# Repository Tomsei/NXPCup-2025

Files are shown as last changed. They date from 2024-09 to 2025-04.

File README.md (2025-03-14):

# NXPCup-2025
Software und Hardware für den NXP-Cup 2025
- **Software Ordner:** gesamter erzeugter Quellcode
- **Hardware Ordner:** Dokumentation der gewählten Hardware mitsamt Recherche

# NXP Cup
- ToDo: Beschreibung des NXP Cups...

Der NXP-Cup ist ein Internationaler Wettbewerb, ausgerichtet vom Unternehmen NXP (Link)...

# Styleguides
### Code
- Sprache (Variablen, Funktionen): Englisch
- Kommentare: Englisch
- Schreibweise: 
    - CamelCase
    - Funktionen / Variablen: starten klein
    - Typ-Klasse: starten groß
    - Variablen:
        - Boolen: Präfix is (isValid)
        - constant: konsequent großschreiben von CONSTANT
    - Leerzeichen zwischen Operatoren:  
    ```x + y``` anstatt ```a+y```; ```[x, y]``` anstatt ```[x,y]```
    - Klammerung: Klammer in gleicher Zeile dahinter
        ```
        function () {
            ...
        }
        ```
  - #defines werden komplett groß geschrieben ```#define NEW_DEFINE_VALUE```
### GIT
- Commits: Englisch
- Dateien: Englisch ```exmpleFileForDemonstration``` 
    - Der Name von Komponenten wird wenn notwendig mit _KOMPONENTENNAME an Datei angehangen
- Verzeichnisse: Englisch
- Wiki: Deutsch
- Issues: Deutsch

<br>
<br>

# Priorisierung der Veränderungen:
Aktuelle Übersicht über die überlegten Veränderungen und die Priorisierung dessen in der Umsetzung.

1. Neue Motoren (Brushless Motoren)
2. Ansteuerungsboard der Motoren (Geschwindigkeitsmessung, Motorkonfiguration)
3. Neue Kamera (Auswertung eines ganzen Bildes, wenn möglich höhere Auflösung
4. Fester Kameramast - Halterung sicherstellen!
5. Neuer Controller (Bevorzug Rasperry PI - Compute Module) → Leistungsstrak
6. Brake Out Board - Darauf kann dann das Compute Module hinterlegt werden
7. WLAN Stick
8. Eine Reihe von Neo LEDS zusammen schalten und nutzen
9. Display Hinzufügen
10. IMU
11. ABS (Durchdrehende Reifen)

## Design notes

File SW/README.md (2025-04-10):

# Software

Dokumentation von allen Erkenntnissen die im Bezug auf die SW des NXP-Cups entstanden sind

Die Ordner strukturieren hierbei die Entwicklungen auf der Kamera (Skripts und Firmwaremodul) und auf dem Teensy (PlattformIO Projekt). 

Im SW-Kit wird eine reduzierte version des Quellcodes festgehalten, der als Vorschlag für ein SW-Kit dienen kann.

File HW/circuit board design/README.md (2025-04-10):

# Platinenentwicklung

Hier werden die für die Platinen relevanten Dateien gespeichert. (Gerber sowie Projektdateien und Dokumentation)

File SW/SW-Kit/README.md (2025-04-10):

# Software-Kit

Das hier enthaltende PlatformIO Projekt und in OpenMV-Script hinterlegte Kameraskript sind die grundlegenden Basiselemente der Software. 

Sie stellen das von mir vorgeschlagene SW-Kit für zukünftige Studierende dar und bietet folgende Implementierung:

1. SPI Verbindung - OpenMV Cam: Die SPI-Verbindung der Kamera, die eine Übertragung von  5 Kamerazeilen durch das Kameraskript ```transferImageLinesSpi.py``` ausführt

2. SPI Verbindung - Teensy: Die Bibliotheksänderungen sowie die Kamera-Datei die zur Annahme der Bilddaten eingesetzt und benötigt werden. Hierbei handelt es sich nur um die reine SPI-Verbindung nicht um die weiteren vorgenommenen Optimierungne.

3. Driving Control - Basisansteuerung von Motor und Servo. 

4. Car Logic - Als Einstiegspunkt der Software / Steuerungen 

Drei und Vier sind auch gewhält worden um erste Ansätze einer möglichen Softwarestruktur aufzuzeigen, was wiederrum für zukünftige Studierende als Inspiration genutzt werden kann.

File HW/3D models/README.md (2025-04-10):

# 3D Modelle

Es liegen alle 3D Modelle in unterschiedlichen Dateiformaten vor. (nicht alle Modelle liegen nicht 3mf / stl vor (müssen noch eigenständig exportiert werden)
Die Freecad-Dateien können eigenständig bearbeitet werden um die 3D Modelle anzupassen.

Teilweise sind zusammengehörige Modelle in einer Datei umgesetzt worden

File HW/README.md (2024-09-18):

# Hardware

Dokumentation über alle Erkentnnisse bezüglich der Hardware.

## Recherche:
Die Recherche zu den unterschiedlichen Komponenten befindet sich im [Wiki des Repositorys](https://github.com/Tomsei/NXPCup-2025/wiki).

## 3D Modelle
Hier werden alle für das Kit notwendigen 3D Modelle gespeichert und notwendige Informationen gegeben.

## Platinendesign
Hier werden alle Platinenentwürfe und für die Platinen relevanten Dateien hinterlegt.

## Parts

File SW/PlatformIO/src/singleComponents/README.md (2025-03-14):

# Single Components
Jeglicher Quellcode dieses Ordners ist lediglich zum austesten der Einzelkomponenten und wird nicht in der finalen Software verwendet.

Dieser Ordner und alle Dateien die dieser beinhaltet sind Basistests der Komponenten, ohne weitere Struktur in der Programmierung. Er dient zum verifizieren, dass alle Komponenten **gleichzeitig** funktionsfähig und ansteuerbar sind.  

Auf der Kamera sollte das Script: ```controlEngineAccespointAsync.py``` ausgeführt werden. Somit kann auch die SPI Verbindung verifiziert werden, in dem das Steuersignal der Motoren weitergeleitet wird.

In der globalConfig.h muss folgende Definition stehen ```#define SINGLE_COMPONENTS_TEST ``` und die Definition zur Analyse auf der Kamera auskommentiert werden

In der Main Datei muss der folgender Quellcode ausgeführt werden:
```c++
#include <Arduino.h>
#include <Wire.h>

#include "configuration/globalConfig.h"
#include "singleComponents/teensy.h"
#include "singleComponents/opticalFlow_PIM453.h"
#include "singleComponents/tofDistanceMeasure_VL53L0X.h"
#include "singleComponents/irObstacleDetection_ARD_LINEFINDER.h"
#include "singleComponents/servo_REELYS2210.h"
#include "singleComponents/motor_PICHLERBOOST18S.h"
#include "singleComponents/imu_SEN0142.h"
#include "singleComponents/camera_OPENMVCAMRT1062.h"
#include "singleComponents/display_CS-ANAVI-DISPLAY1.h"
#include "singleComponents/ioExpander_MCP23017.h"
#include "singleComponents/poti.h"
#include "singleComponents/ledStrip_Adafruit1426.h"

//Just testing variable for engine control
bool globalEngineState;

void setup() {

  // put your setup code here, to run once:
  CONSOLE.begin(115200);
  Wire.begin();
  SingleComponent::setupOpticalFlow();
  SingleComponent::setupTofDistanceMeasure();
  SingleComponent::setupArdLinefinder();
  SingleComponent::setupImu();
  SingleComponent::setupServo();
  SingleComponent::setupMotor();
  SingleComponent::setupCamera();
  SingleComponent::setupDisplay();
  SingleComponent::setupIoExpander();
  SingleComponent::setupLedStrip();

  //Just testing variable
  globalEngineState = false;
}

void loop() {
  // put your main code here, to run repeatedly:
  SingleComponent::runOpticalFlow();
  SingleComponent::runTofDistanceMeasure();
  SingleComponent::runArdLineFinder();
  SingleComponent::runImu();
  SingleComponent::runServo();
  SingleComponent::runMotor();
  SingleComponent::runCamera();
  SingleComponent::runDisplay();
  SingleComponent::runIoExpander();
  SingleComponent::runPoti();
  SingleComponent::runLedStrip();
} 
```

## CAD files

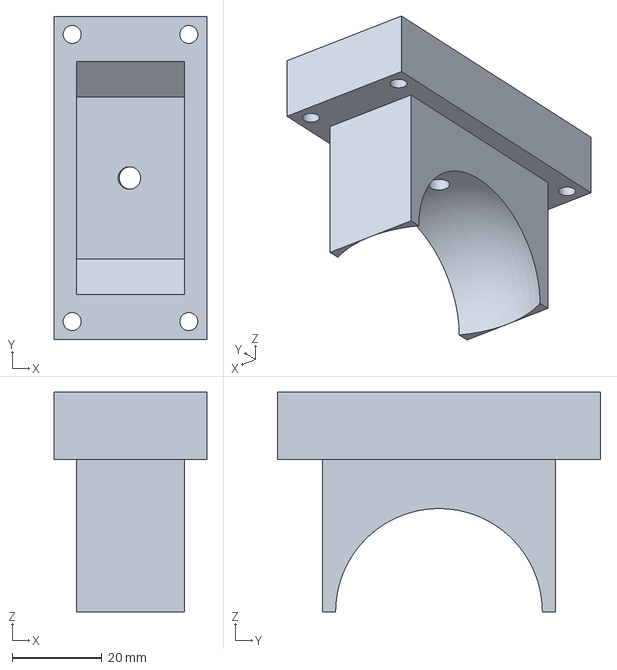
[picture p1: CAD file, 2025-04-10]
HW/3D models/3mf/Gussform_Außen1.3mf
34.0 x 72.0 x 49.0 mm

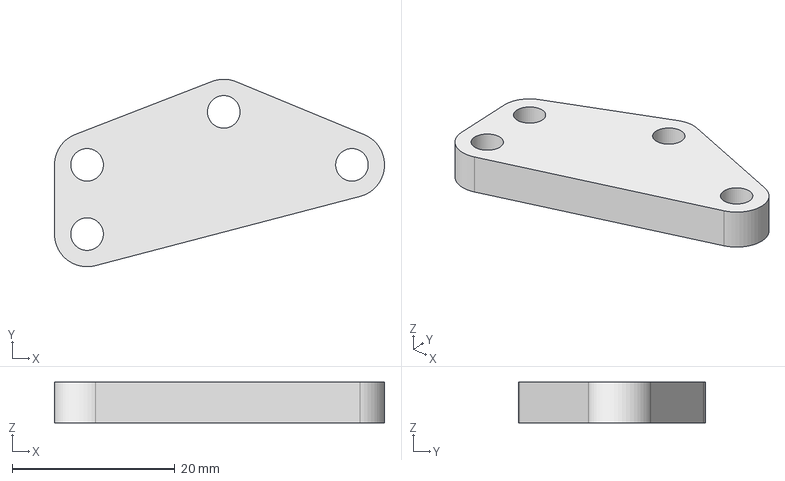
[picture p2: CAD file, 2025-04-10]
HW/3D models/Freecad/Halterung_Spannungswandler.FCStd
40.5 x 23.0 x 5.00 mm

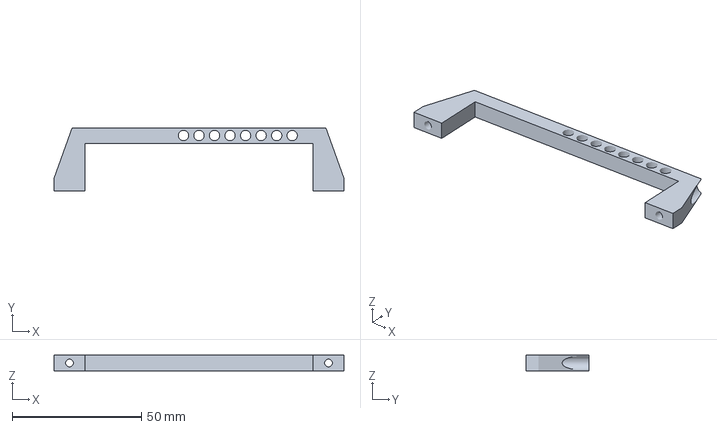
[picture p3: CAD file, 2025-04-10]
HW/3D models/3mf/Lenkachse_oben.3mf
112.0 x 24.5 x 6.00 mm

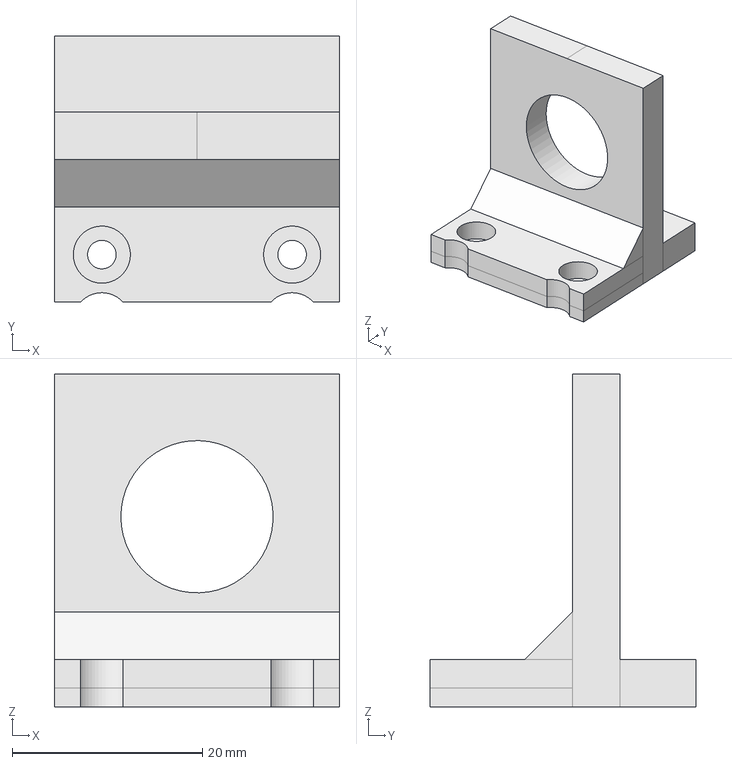
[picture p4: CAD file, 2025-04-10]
HW/3D models/Freecad/Halterung_Powerswitch_ESC.FCStd
30.0 x 28.0 x 35.0 mm

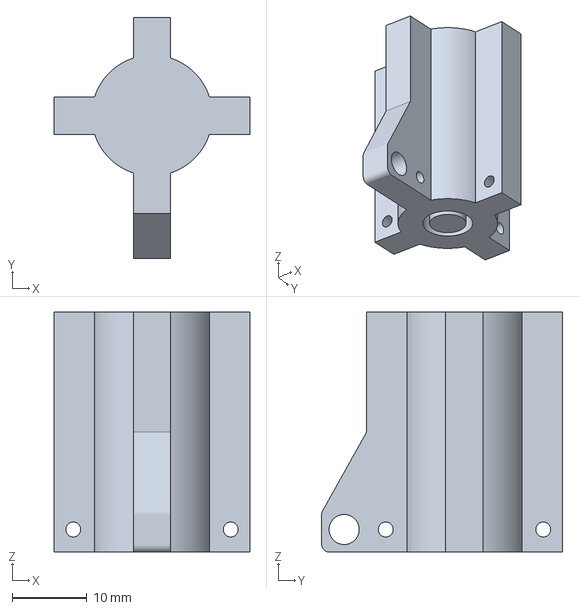
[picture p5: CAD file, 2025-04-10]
HW/3D models/3mf/Halterung_Kamera_1_alt.3mf
26.1 x 32.1 x 32.0 mm

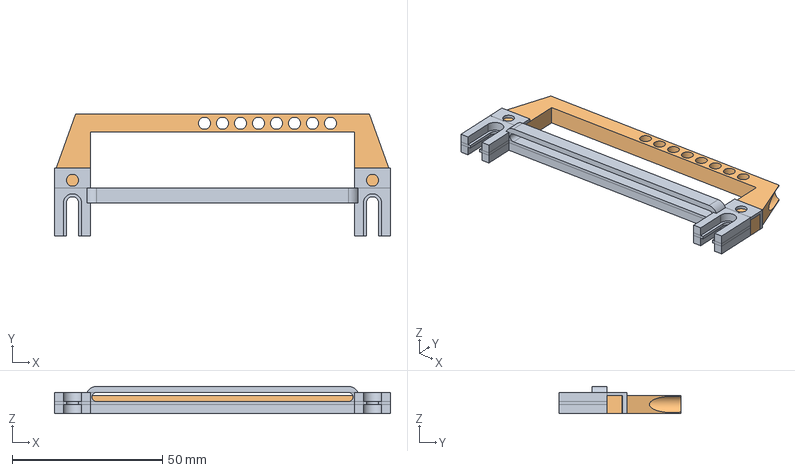
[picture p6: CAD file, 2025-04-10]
HW/3D models/Freecad/Lenkachse.FCStd
112.0 x 40.5 x 9.01 mm
Körper
Körper001

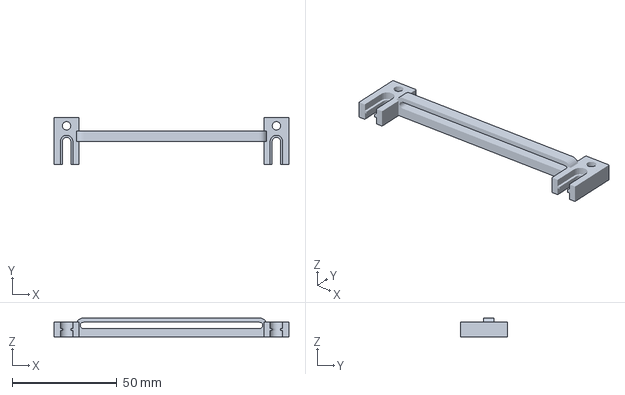
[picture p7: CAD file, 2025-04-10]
HW/3D models/3mf/Lenkachse_unten.3mf
112.0 x 22.5 x 9.01 mm

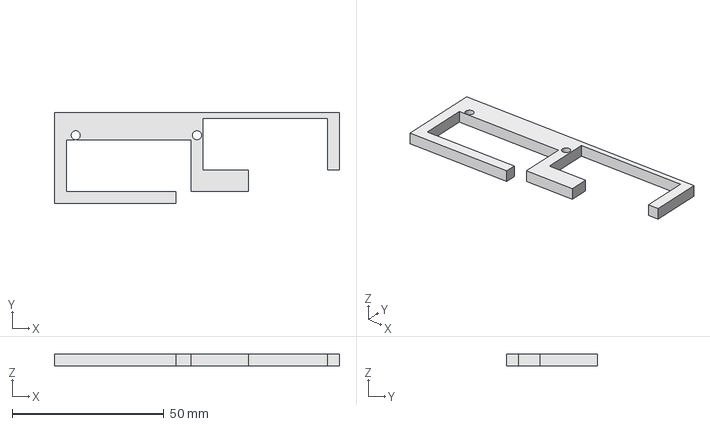
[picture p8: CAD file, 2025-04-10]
HW/3D models/Freecad/Halterung_IR_Hinderniserkennung.FCStd
94.0 x 30.0 x 4.00 mm

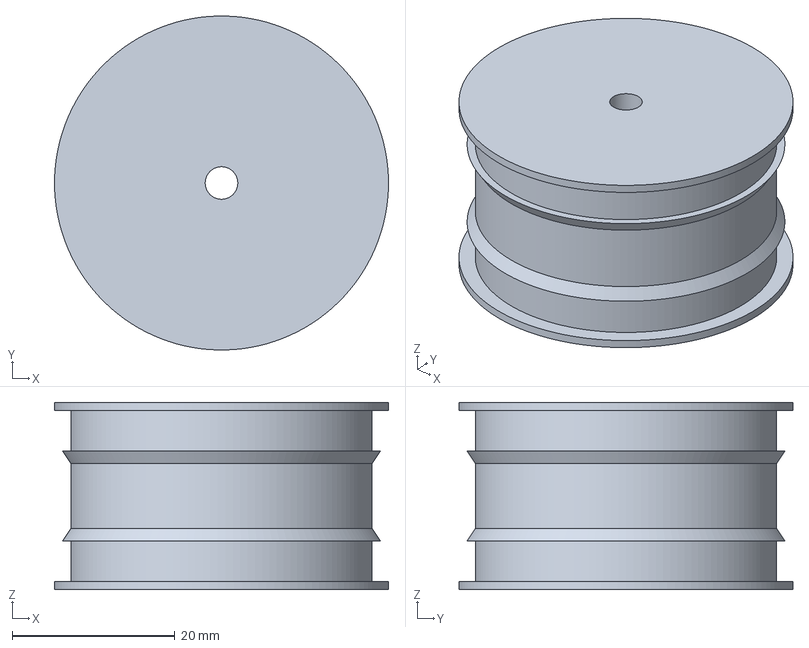
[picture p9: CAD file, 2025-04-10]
HW/3D models/3mf/Gussform_Innenrad.3mf
41.0 x 41.0 x 23.0 mm

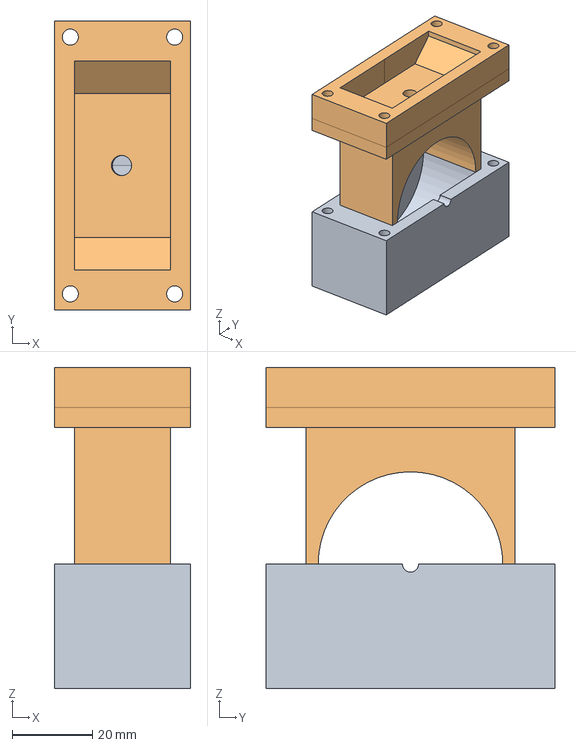
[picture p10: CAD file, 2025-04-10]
HW/3D models/Freecad/Gussformen.FCStd
34.0 x 72.0 x 80.0 mm
V4_5
V4_4

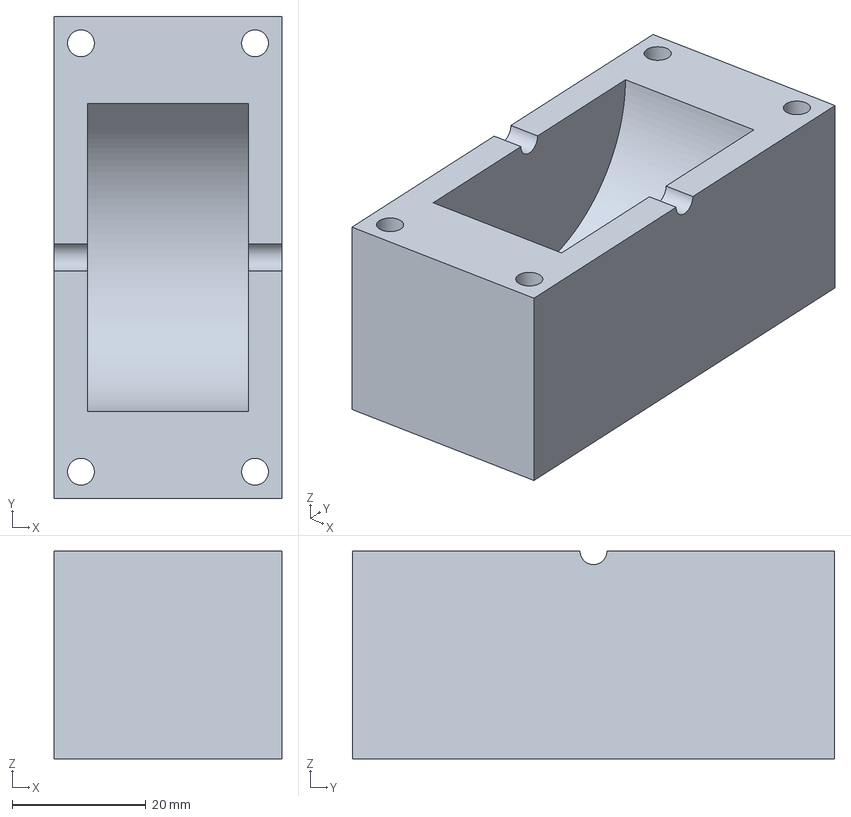
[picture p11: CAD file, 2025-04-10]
HW/3D models/3mf/Gussform_Außen2.3mf
34.0 x 72.0 x 31.0 mm

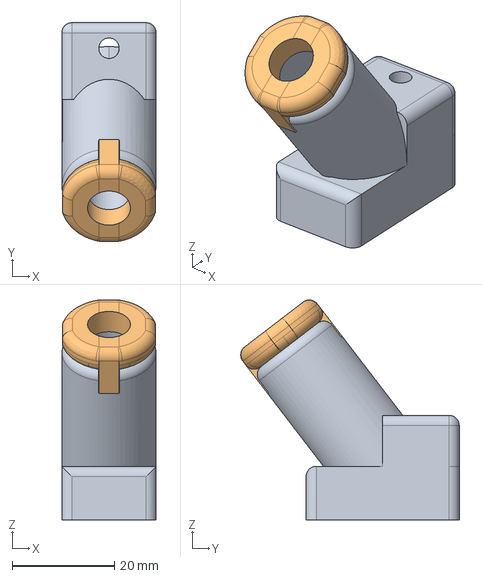
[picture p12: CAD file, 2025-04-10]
HW/3D models/Freecad/Halterung_Kameramast_Neu.FCStd
18.5 x 42.8 x 43.1 mm

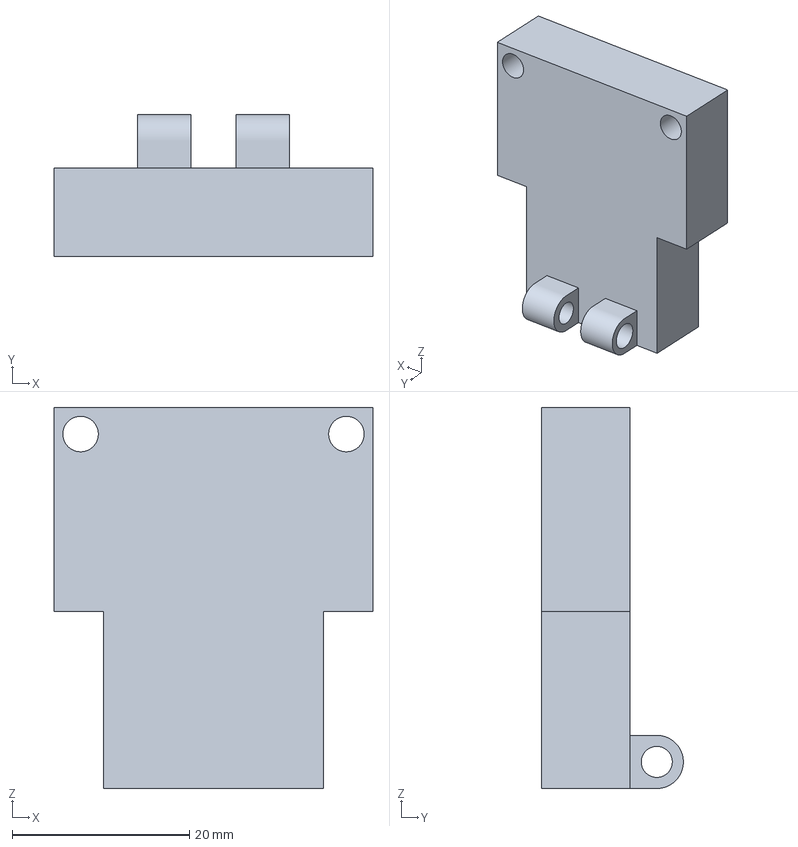
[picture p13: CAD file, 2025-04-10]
HW/3D models/3mf/Halterung_Kamera_2_alt.3mf
36.0 x 16.0 x 43.0 mm

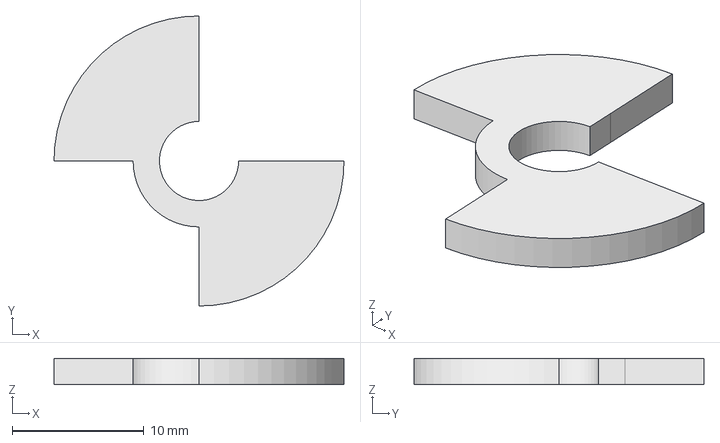
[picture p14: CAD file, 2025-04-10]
HW/3D models/Freecad/Rad_IR_Hinderniserkennung.FCStd
22.0 x 22.0 x 2.00 mm

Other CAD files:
HW/3D models/3mf/Halterung_Kameramast_clip_Neu.3mf
HW/3D models/Freecad/Halterung_Platine_Vorne.FCStd
HW/3D models/3mf/Gussformen_Gesamt.3mf
HW/3D models/Freecad/Halterung_Kameramast_alt.FCStd
HW/3D models/3mf/Halterung_Display.3mf
HW/3D models/3mf/Halterung_IR_Hinderniserkennung.3mf
HW/3D models/3mf/Halterung_Kamera_Neu.3mf
HW/3D models/3mf/Halterung_Kameramast_Neu.3mf
HW/3D models/3mf/Halterung_Kameramast_alt.3mf
HW/3D models/3mf/Halterung_Motor.3mf
HW/3D models/3mf/Halterung_Optical_Flow.3mf
HW/3D models/3mf/Halterung_Powerswitch_ESC.3mf
HW/3D models/3mf/Halterung_Relais_Spannungswandler.3mf
HW/3D models/3mf/Halterung_Spannungswandler.3mf
HW/3D models/3mf/Halterung_ToF_Distanzsensor.3mf
HW/3D models/3mf/Rad_IR_Hinderniserkennung.3mf
HW/3D models/3mf/Radhalterung.3mf
HW/3D models/Freecad/Halterung_Display.FCStd
HW/3D models/Freecad/Halterung_Kamera_Neu.FCStd
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

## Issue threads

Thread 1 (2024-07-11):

Recherche - HW Komponenten

Tomsei, 2024-07-11:
Recherche nach allen Hardware Komponenten

- [x] Bodenplatte
- [x] Räder
- [x] Lenksystem
- [x] Prozessor
- [x] Motoren
- [x] Motortreiber - ESC
- [x] Geschwindigkeitsmessung
- [x] Servo
- [x] Kamera
- [x] Distanzmesser
- [x] IMU
- [x] Display
- [x] LED-Stribes-Anzeige

Closed 2024-10-23.

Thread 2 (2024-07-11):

Bestellen - HW Komponenten

Tomsei, 2024-07-11:
Bestellen der gewünschten Hardware Komponenten

- [x] Bodenplatte
- [x] Räder
- [x] Lenksystem
- [x] Prozessor
- [x] Motoren
- [x] Motortreiber - ESC
- [x] Geschwindigkeitsmessung
- [x] Servo
- [x] Kamera
- [x] Distanzmesser
- [x] IMU
- [x] Display
- [x] LED-Stribes-Anzeige

Closed 2024-10-23.

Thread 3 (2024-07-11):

Austesten der HW-Komponenten

Tomsei, 2024-07-11:
Das Austesten und die Inbetriebnahme der gewählten HW-Komponenten.
Gilt als Erfüllt sobald alle HW-Komponenten irgendwie funktionsfähig sind (Werte ausgeben etc. )

Tomsei, 2024-10-23:
Alles wurde ausgetestet mit der Ausnahme des Displays (Lieferverzögerungen)

Closed 2024-10-23.

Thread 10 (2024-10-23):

Strukturierte Implementierung - Komponenten (Allgemein)

Tomsei, 2024-10-23:
Eine Strukturierte Implementierung erarbeiten, die für die Umsetzung der einzelnen Komponenten gilt und verwendet werden kann

Tomsei, 2025-01-20:
Software Struktur ist erarbeitet. Alle weiteren Entwicklungen sollen in der erarbeiteten Struktur integriert werden und diese direkt bei der Entwicklung berücksichtigen!

Closed 2025-01-20.

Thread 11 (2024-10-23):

WiFi - Steuerungsmöglichkeit

Tomsei, 2024-10-23:
Das WiFi der OpenMV Cam nutzen um ein Steuerungsinterface zu erstellen, mit welchem der Motor vom Fahzeug an und abgeschaltet werden kann.

Tomsei, 2024-11-07:
Es existiert eine sehr einfache, aber trotzdem funktionale Steuerungsmethode zum an und abstellen der Motoren

Tomsei, 2024-11-07:
Es existiert eine sehr einfache, aber trotzdem funktionale Steuerungsmethode zum an und abstellen der Motoren

Closed 2024-11-07.

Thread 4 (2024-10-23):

WiFi - Daten Streaming

Tomsei, 2024-10-23:
Umsetzung einer Möglichkeiten die Sensordaten und Fahrdaten des Fahrzeugs über WiFi zu übertragen und im Browser anzuzeigen.

Um dies zu ermöglichen müssen zunächst erstmal Daten vom Teensy auf die Kamera übertragen werden!

Tomsei, 2025-03-08:
Durch die alternative Bluetooth Verbindung vom Teensy ist keine WiFi Datenübertragung über die Kamera mehr notwendig.

Zum einen ist die Implementierung mit Hilfe des Bluetooth Moduls einfacher. Hinzukommt dass keine weitere Rechenkapazität der Kamera aufgewendet werden muss

Closed 2025-03-08.

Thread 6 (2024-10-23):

Komponentenintegration auf Platine

Tomsei, 2024-10-23:
Jegliche Komponente ist mit der erstellten Platine Funktionsfähig und kann angesprochen, ausgelesen und angesteuert werden.

Tomsei, 2024-11-07:
Es wurden alles Komponenten mit der Platine / Anschlüsse der Platine ausgetestet mit der Ausnahme von:

1. LED Stripe
2. Spare I2C

Tomsei, 2024-12-10:
Alles wurde ausgetestet außer die beiden Spare I2C.

Closed 2024-12-10.

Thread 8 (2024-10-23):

Ziel Basis Funktionalitäten - Fahrzeug Fahrt

Tomsei, 2024-10-23:
Das Fahrzeug fährt Gerade aus, Links und Rechts und ließt dabei alle verwendeten Sensoren aus (Kamera, ToF, Optical Flow, Ard Line Finder, IMU)

Tomsei, 2024-11-07:
Abschluss Status: Funktionsfähig, fahren ist in alle Richtungen (rechts, links, geradeaus möglich). Parallel werden Sensordaten ausgelesen. Von der Kamera wird über SPI ein Steuersignal versendet zum starten und stoppen des Autos.

Tomsei, 2024-11-07:
Abschluss Status: Funktionsfähig, fahren ist in alle Richtungen (rechts, links, geradeaus möglich). Parallel werden Sensordaten ausgelesen. Von der Kamera wird über SPI ein Steuersignal versendet zum starten und stoppen des Autos.

Closed 2024-11-07.

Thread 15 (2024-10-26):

Strukturierte Implementierung - Optical Flow Sensor

Tomsei, 2024-10-26:
Die Implementierung des Optical FLow Sensors vervollständigen und strukturieren, sodass eine selbsterklärende Nutzung der Software zum Optical FLow Sensor möglich ist.

Closed 2025-01-20.

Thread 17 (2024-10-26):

Strukturierte Implementierung - ToF Distanzmesser

Tomsei, 2024-10-26:
Die Implementierung des ToF Distanzmesser vervollständigen und strukturieren, sodass eine selbsterklärende Nutzung der Software zum ToF Distanzmesser möglich ist.

Closed 2025-01-20.

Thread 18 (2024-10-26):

Strukturierte Implementierung - IR Hindernissensoren (2)

Tomsei, 2024-10-26:
Die Implementierung beider IR Hindernissensoren vervollständigen und strukturieren, sodass eine selbsterklärende Nutzung der Software für die IR Hindernissensore möglich ist.

Closed 2025-01-20.

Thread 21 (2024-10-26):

Strukturierte Implementierung - Kameraschnittstelle (Teensy)

Tomsei, 2024-10-26:
Die Implementierung der Kameraschnittstelle (SPI) vervollständigen und strukturieren, sodass eine selbsterklärende Nutzung der Software zur Kameraschnittstelle möglich ist.

Tomsei, 2025-03-08:
Ein klares Kommunikationsprotokoll wurde noch nicht entwickelt, es ist jedoch eine zuverlässige Übertragung der Bilddaten mit einer Swap-Buffer Speicherung implementiert worden.

Die Schnittstelle ist aufgeräumt und strukturiert. Als offene Erweiterung steht die Strukturierung der Datenkommunikation im Raum um Beispielsweise noch zusätzliche Daten zu versenden. Hierfür wird ein eigenes Issue eröffnet

Closed 2025-03-08.

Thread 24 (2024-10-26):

Strukturierte Implementierung - DipSwicht - Button - IOExpander

Tomsei, 2024-10-26:
Die Implementierung vom IOExpander mitsamt Dipswitch und Button vervollständigen und strukturieren, sodass eine selbsterklärende Nutzung der Software möglich ist.

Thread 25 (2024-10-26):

Kantenerkennung

Tomsei, 2024-10-26:
Implementierung der Kanten / Linienerkennung der Kamera.

Ziel ist das Erkennen der Streckenbegrenzung bei unterschiedlichen Lichtbedingungen!

Stichwort: Sobeloperator / vergleichbare Algorithmen

Tomsei, 2024-11-22:
Basisimplementierung mit Sobeloperator ist umgesetzt

Closed 2024-11-22.

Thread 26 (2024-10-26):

Basis Streckenmittelpunkt Berechnung

Tomsei, 2024-10-26:
Identifikation des Streckenmittelpunktes welcher für die Fahrt angesteuert werden kann.

Gedanke: Je nach Position des Autos Punkt ggf. anpassen

Tomsei, 2024-11-07:
Hinweis: In der ersten Implementierung soll alles zunächst auf einer gewählten Zeile passieren

Tomsei, 2024-11-22:
Update 22.11: Mittelpunkt kann berechnet werden. Startposition der Berechnung nach links und rechts muss jedoch noch abhängig von der "Streckenführung" angepasst werden (kurve / eingelenkt)

Closed 2025-01-20.

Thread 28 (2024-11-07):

Mehrere Python Scripts auf Kamera

Tomsei, 2024-11-07:
Um nicht ein riesen Großes Main Python Script auf der Kamera zu haben soll erarbeitet werden, wie die Nutzung von mehreren strukturierten Python Scripten ermöglicht werden kann.

Tomsei, 2025-03-08:
Ist aufgrund der Implementierungen in der Kamera Firmware nicht mehr notwendig geworden. Die genutzten Pythonskripte bieten in sich selbst ausreichend Struktur. Die meisten Implementierungen konnten auf die Kamerafirmware umgelagert werden

Tomsei, 2025-03-08:
Ist aufgrund der Implementierungen in der Kamera Firmware nicht mehr notwendig geworden. Die genutzten Pythonskripte bieten in sich selbst ausreichend Struktur. Die meisten Implementierungen konnten auf die Kamerafirmware umgelagert werden.

Closed 2025-03-08.

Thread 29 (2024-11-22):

Strukturierte Implementierung - Kantenerkennung

Tomsei, 2024-11-22:
Erfüllt sobald die Kantenerkennung im Gesamtsystem mit der fertigen Struktur implementiert ist.

Tomsei, 2025-03-08:
Sowohl die Kantenerkennung auf dem Teensy als auch in der Kamera Firmware selbst ist strukturiert

Closed 2025-03-08.

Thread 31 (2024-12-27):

Slave SPI Antwort (Teensy -> Kamera Kommunikation)

Tomsei, 2024-12-27:
Entwicklung einer Kommunikationsmöglichkeit um Daten vom Teensy auf die Kamera zu übertragen.

**Mögliche Relevanz:**
Könnte Relevant werden wenn auf der Kamera noch zusätzliche Informationen benötigt werden, wie beispielsweise:
- Dynamische Auswahl der gesendeten Bildzeilen (Übertragen vom Teensy welche Bildzeilen gesendet werden sollen)
- weitere Daten für den Kameraalgorithmus
- Datastreaming von Programmdaten über die WiFi Verbindung der Kamera (Aktuell wird alternative durch WiFi Modul ausgetestet)

**Aktuell:**
Kamera ist aktuell ausschließlich als Bildanalyse eingeplant und umgesetzt. Fahrentscheidungen werden auf dem Teensy berechnet. Entsprechend sind aktuell keine Daten nach oben notwendig.

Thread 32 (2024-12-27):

Basis Implementierung WiFi Modul

Tomsei, 2024-12-27:
Umsetzung und Anschluss des WiFI Moduls für den Teensy um eine WLAN Verbindung unabhängig von der Kamera aufbauen zu können. Soll sowohl für die Steuerung als auch für mögliches Data Streaming genutzt werden können

Tomsei, 2025-03-08:
Bluetooth Verbindung hergestellt und das übertragen von Live Daten ist möglich. Die Steuerung des Fahrzeugs ist jedoch noch nicht möglich. Kann noch optional bei zusätzlicher Zeit umgesetzt werden

Closed 2025-03-08.

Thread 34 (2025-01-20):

Anpassung der Kamera Firmware

Tomsei, 2025-01-20:
Der Algorithmus zur Auswertung der Bildzeilen ist auf der Kamera ausführbar wordurch nur noch die Ergebnisse versendet werden müssen und nicht mehr ein gesamtes Bild.

Tomsei, 2025-03-08:
Die Kamera Firmware ist angepasst nutzbar und wird nur noch abhängig von den gewünschten Optimierungen verbessert

Closed 2025-03-08.

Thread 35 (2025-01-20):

Fertigstellung der "Driving Control"

Tomsei, 2025-01-20:
Jegliche Aufgaben bezüglich der Fahrsteuerung wie beispielsweise das erreichen einer spezifischen Geschwindigkeit, das korrekte Ansteuern der Servoausrichtung und vergleichbares

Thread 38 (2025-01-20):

Fertigstellund der "Servo Control"

Tomsei, 2025-01-20:
Prüfen und erstellen einer korrekten und Präzisen Servoausrichtung in Abhängigkeit zum Winkel der gefahren werden soll!

Tomsei, 2025-03-08:
Die Berechnung des Lenkwinkels aus den Bilddaten ist zuverlässig und solide. Die Distanz zur Mitte wird erst normiert und anschließend quadriert, wordurch die Werte zum Lenken für den Servor berechnet werden

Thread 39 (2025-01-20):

Basisimplementierung der Car Logik

Tomsei, 2025-01-20:
Die Software Struktur so erweitern, dass eine Car Logik existiert, welche die jeweiligen Unterbereiche des Fahrzeugs miteinander verknüpft und somit die gesamt Steuerung des Autos ermöglicht.

Tomsei, 2025-03-08:
Die Car Logic ist in der Basis implementiert, wird aber noch abhängig von den auftretenden Optimierungen weiter verbessert

Closed 2025-03-08.

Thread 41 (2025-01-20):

Fertigstellung Sensorauswertung

Tomsei, 2025-01-20:
Aktueller Stand: Die Raw Sensordaten können angezeigt und geschrieben werden.

Die Sensoren sollten für die Fahrt jedoch noch verwendet werden und zum Einsatz kommen!

Dieses Issue gilt als abgeschlossen wenn jede Sensorverwertung geprüft und implementiert wurde. Entsprechend gibt es die weiteren Sub-Issues die sich mit den jeweiligen Sensoren im einzelnen befassen

Closed 2025-07-16.

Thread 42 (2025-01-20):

Sensorauswertung - Optical Flow nutzen

Tomsei, 2025-01-20:
Die Werte des Optical Flow Sensors sinnvoll auswerten und beim Fahrverhalten nutzen!

Tomsei, 2025-03-08:
Unterschiedliche Möglichkeiten zur Nutzung des Optical Flow Sensors wurden ausprobiert. Leider konnte keine variante nutzbare Werte liefern. Entsprechend kommt der Optical Flow Sensor nicht für die Geschwindigkeitsmessung zum Einsatz

Tomsei, 2025-03-08:
Unterschiedliche Möglichkeiten zur Nutzung des Optical Flow Sensors wurden ausprobiert. Leider konnte keine variante nutzbare Werte liefern. Entsprechend kommt der Optical Flow Sensor nicht für die Geschwindigkeitsmessung zum Einsatz.

Closed 2025-03-08.

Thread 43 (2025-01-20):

Sensorauswertung - ToF Distanz Sensor nutzen

Tomsei, 2025-01-20:
Die Werte des ToF-Sensors sinnvoll auswerten und beim Fahrverhalten nutzen!

Tomsei, 2025-03-08:
Sensor Daten kommen zum Einsatz um for Objekten stehen zu bleiben. Die Präzise optimierung folgt sobald die Ziellienerkennung durchgeführt wurde

Closed 2025-03-08.

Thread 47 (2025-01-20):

Verbesserung der LED Visualisierung

Tomsei, 2025-01-20:
Ermöglichen dass eine Einzelne LED angesteuert werden kann (Signalisierung von)

Ermöglichen das eine Zahl angezeigt werden kann...

Weitere optionale Visualiserungsmöglichkeiten!

Tomsei, 2025-03-08:
Einzelne LEDS können angesteuert werden, sowie eine Zahl gemappt auf eine einstellbare range. Weitere Darstellungen sind denkbar und werden ergänzt.

Aktuelles Problem: Update der LEDS führt noch zu fehlern wegen Verzögerungen bei der Ansteuerung
- muss noch mit Timing System abgestimmt werden

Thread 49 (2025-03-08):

Strukturierung der SPI Daten

Tomsei, 2025-03-08:
Den Datentransfer mit Kontroll Bits / einer Kontroll Struktur anreichern und diese nutzen.

Die ersten Ansätze existieren bereits bei der Kameraanalyse in der Kamerafirmware.

Wird notwendig um eine erkannte Ziellinie zu übertragen!

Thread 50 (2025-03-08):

Optimierungen Kamera Firmware

Tomsei, 2025-03-08:
Jegliche offenen Verbesserung der Kamerafirmware um potentiell noch mehr FPS zu ermöglichen.

Jegliche weitere Veränderung / Erweiterung die noch für die Nutzung benötigt wird.

Möglichkeiten:
- track center direkt bei der Sobel Berechnung berechnen (nur bis zu ersten Sobel Kante laufen und den Rest ignorieren)

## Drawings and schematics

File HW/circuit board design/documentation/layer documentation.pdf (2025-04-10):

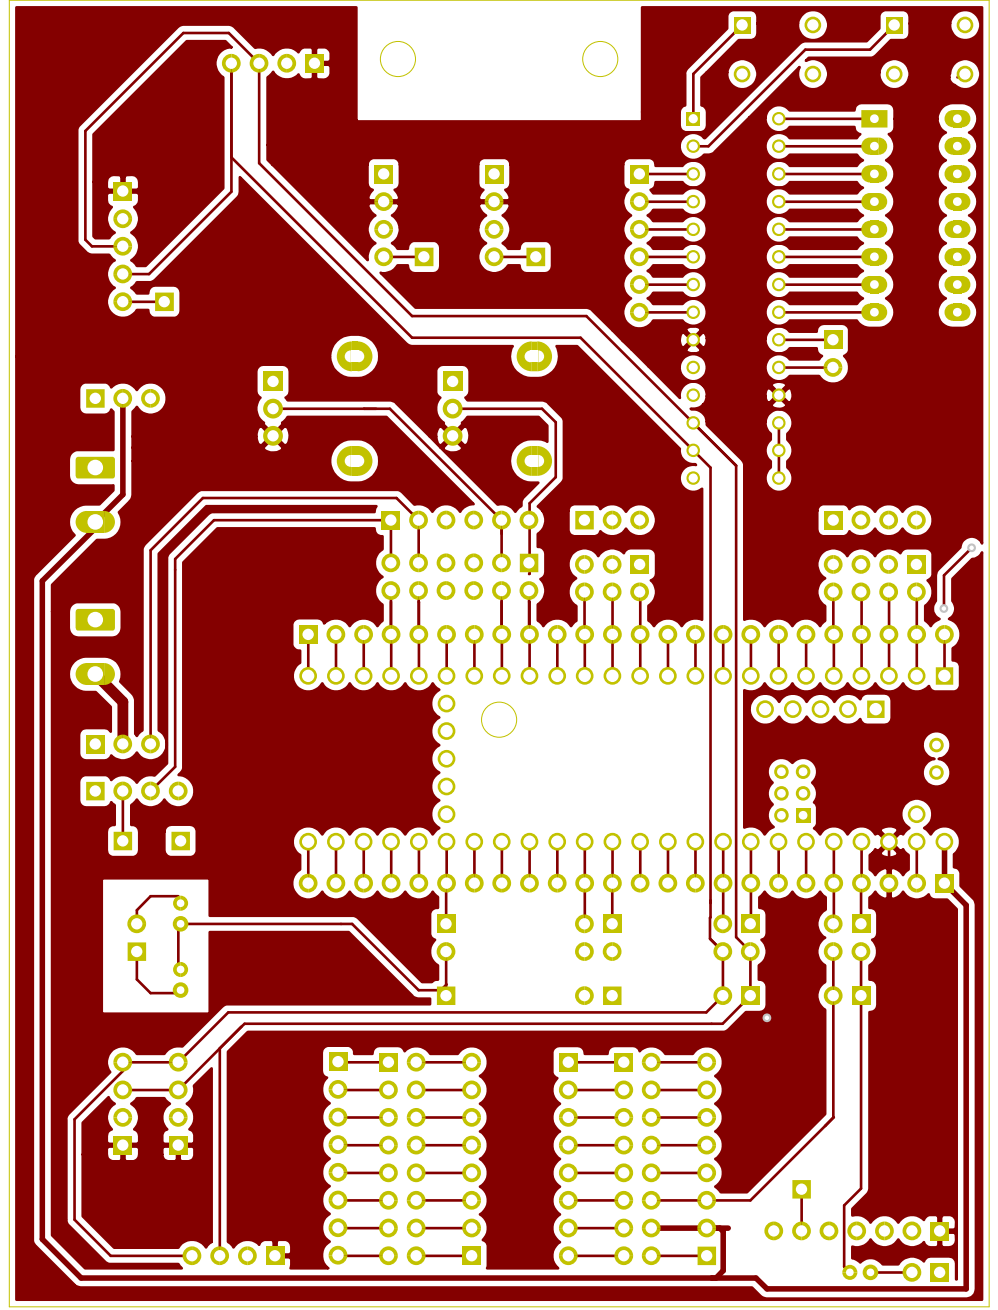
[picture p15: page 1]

0 | 0

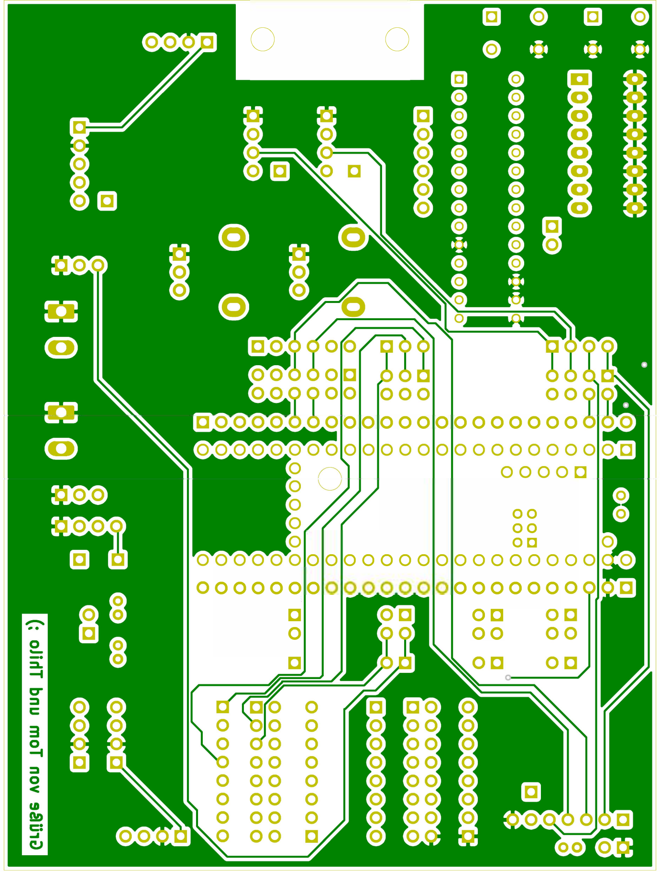
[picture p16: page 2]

0000000000000

00
00
oc
000000000000000
000000 | 000000

C
0 | oc
| 00

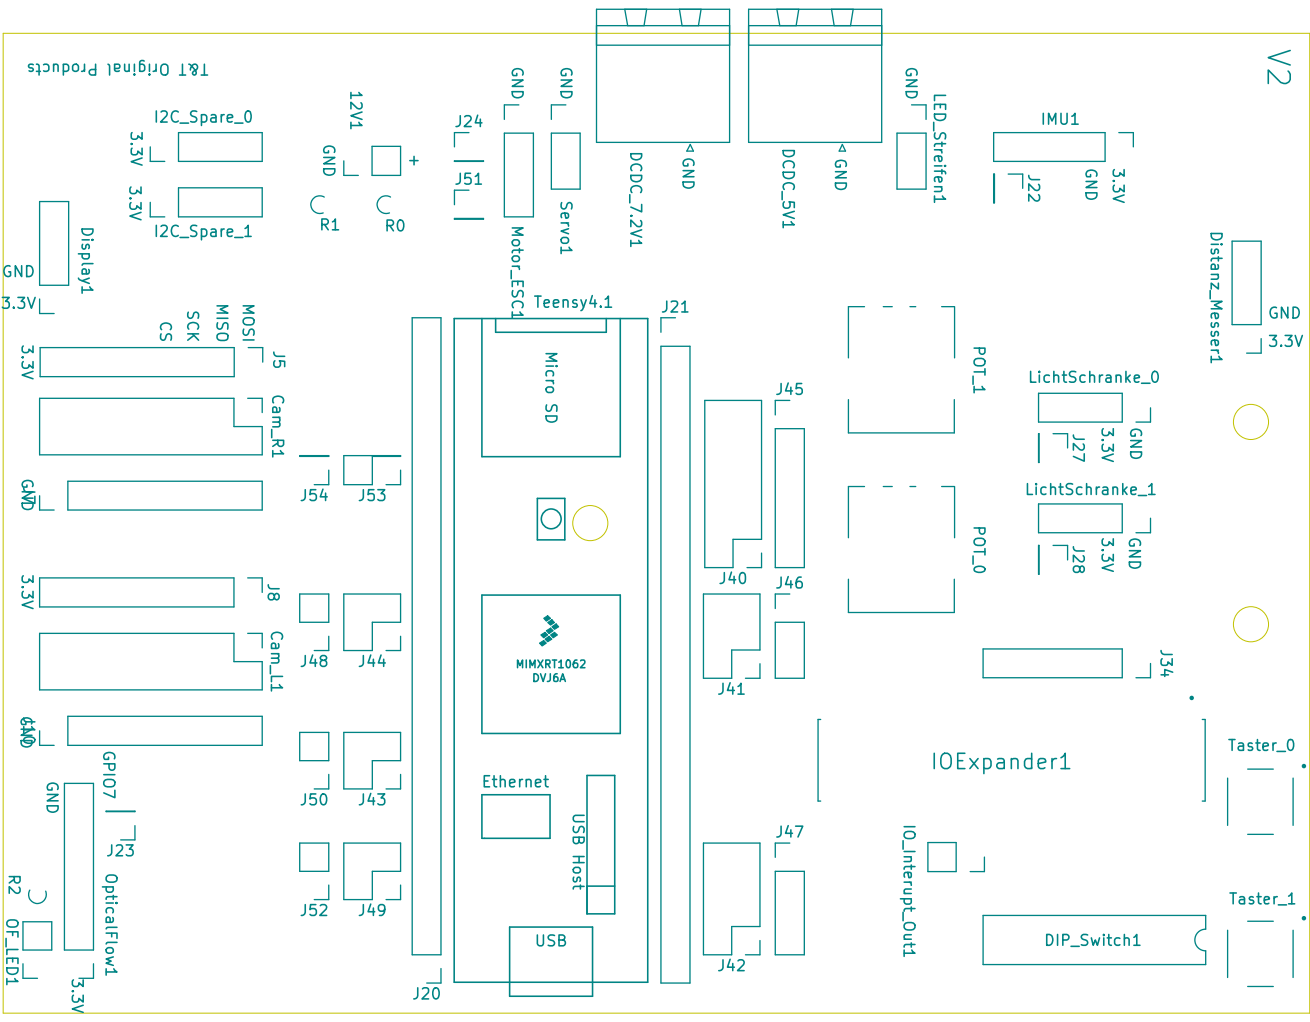
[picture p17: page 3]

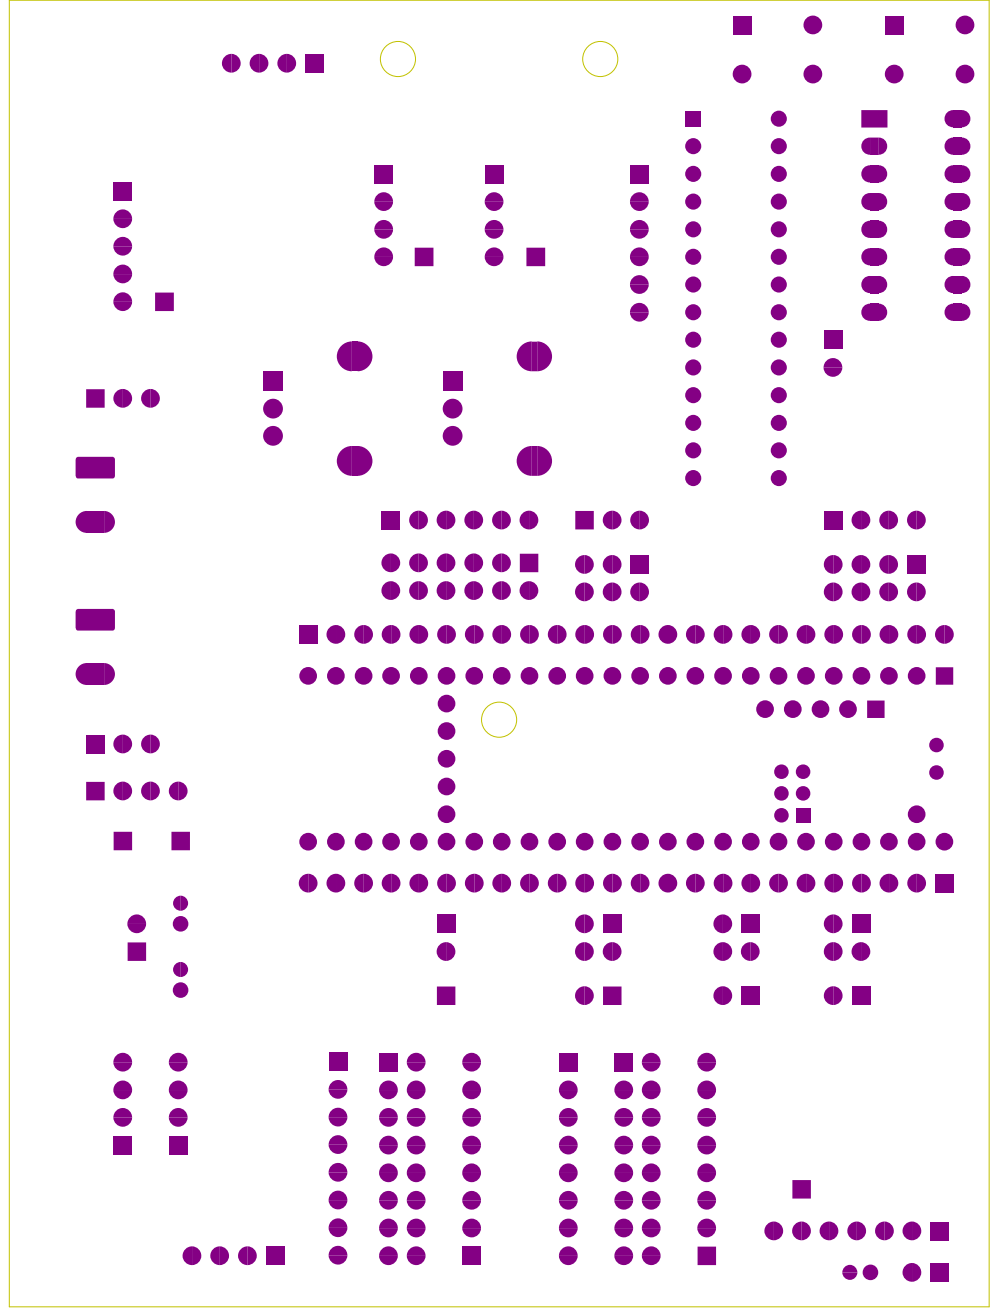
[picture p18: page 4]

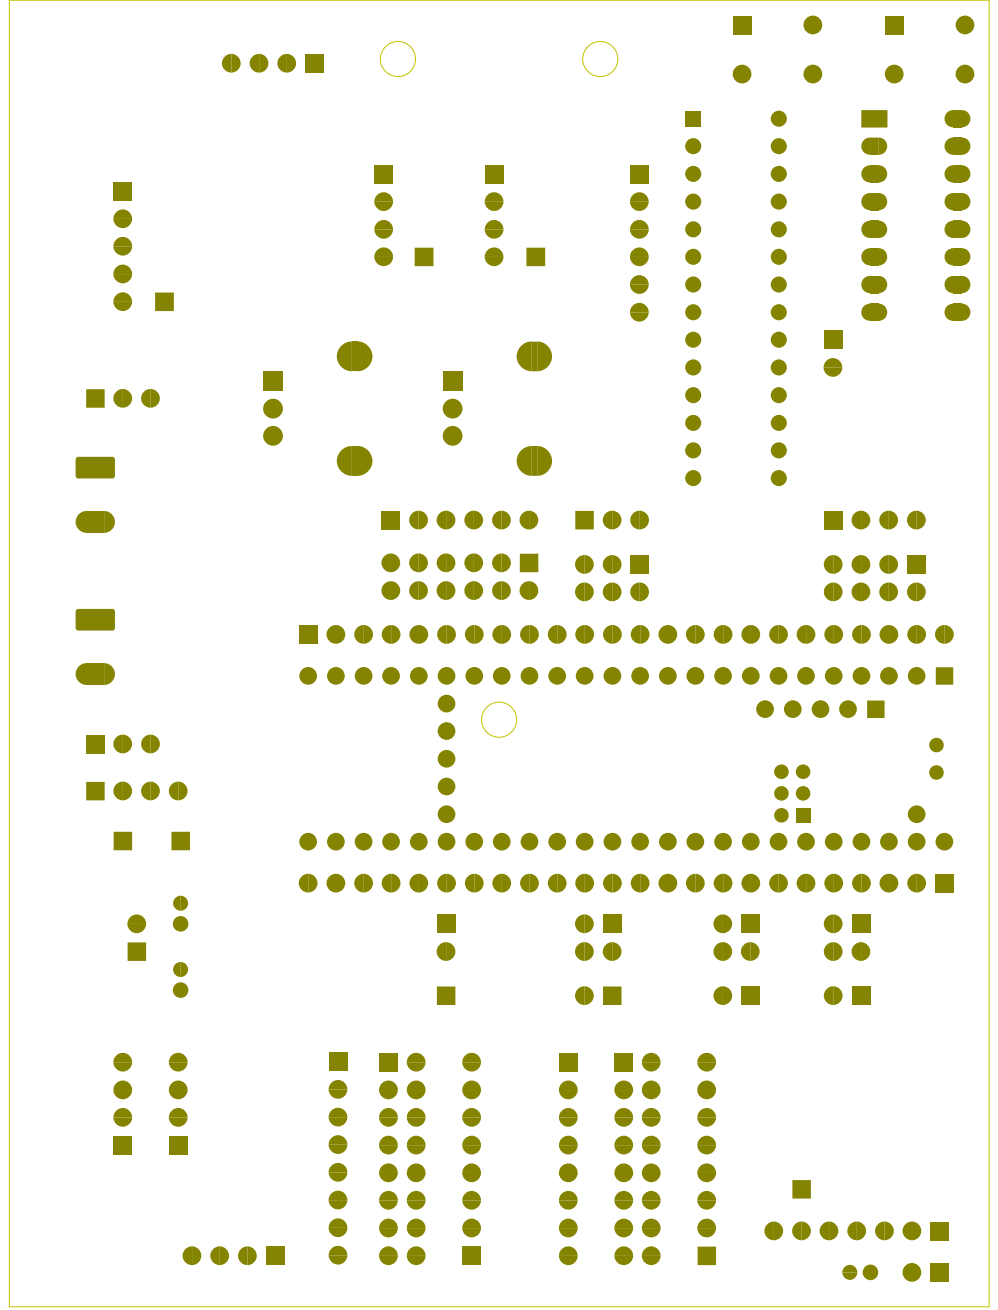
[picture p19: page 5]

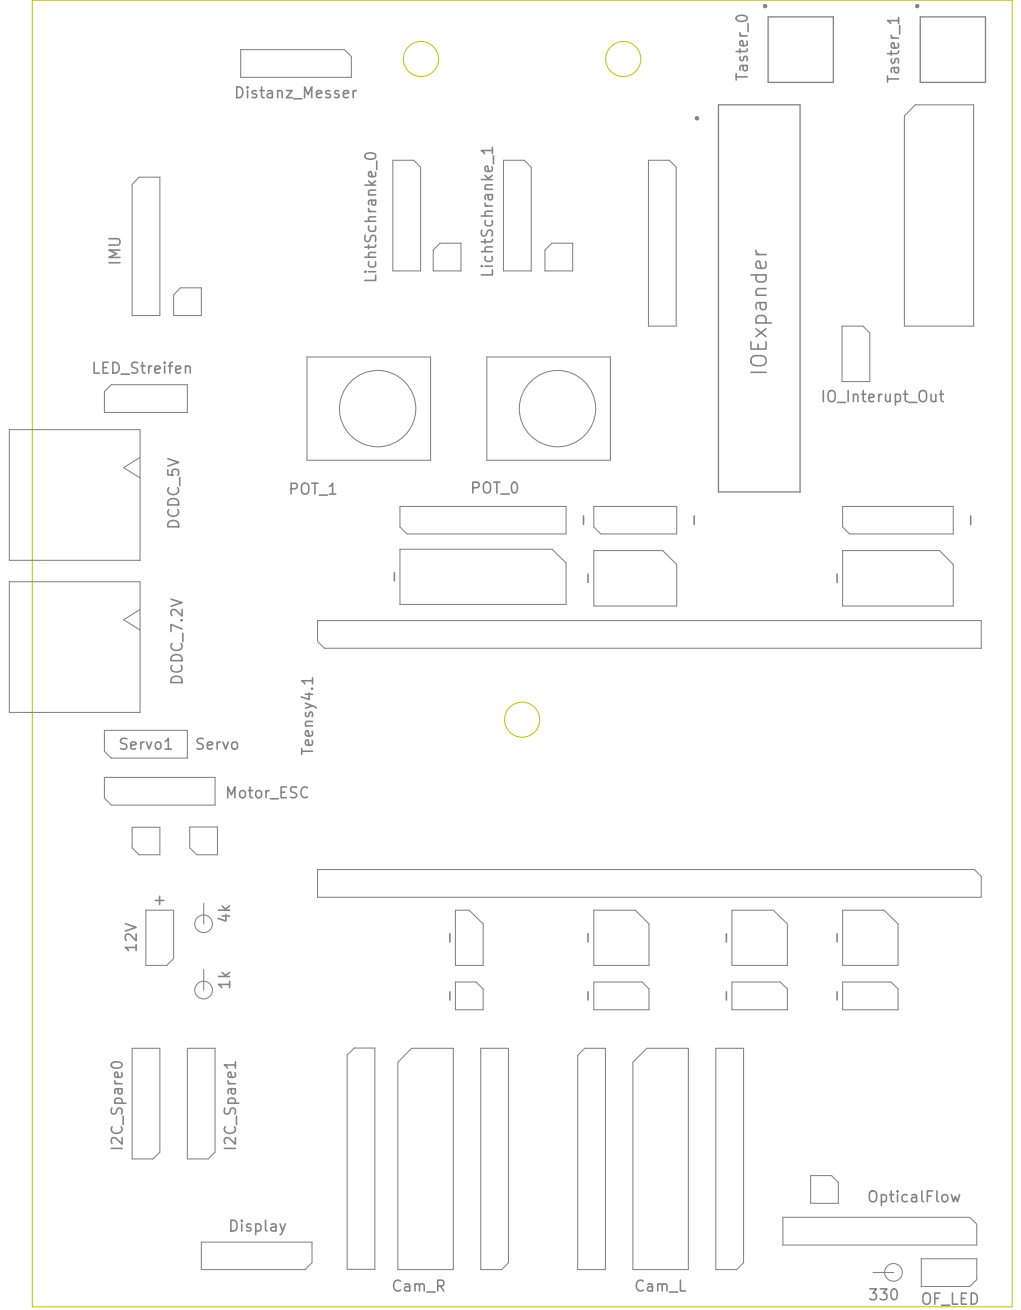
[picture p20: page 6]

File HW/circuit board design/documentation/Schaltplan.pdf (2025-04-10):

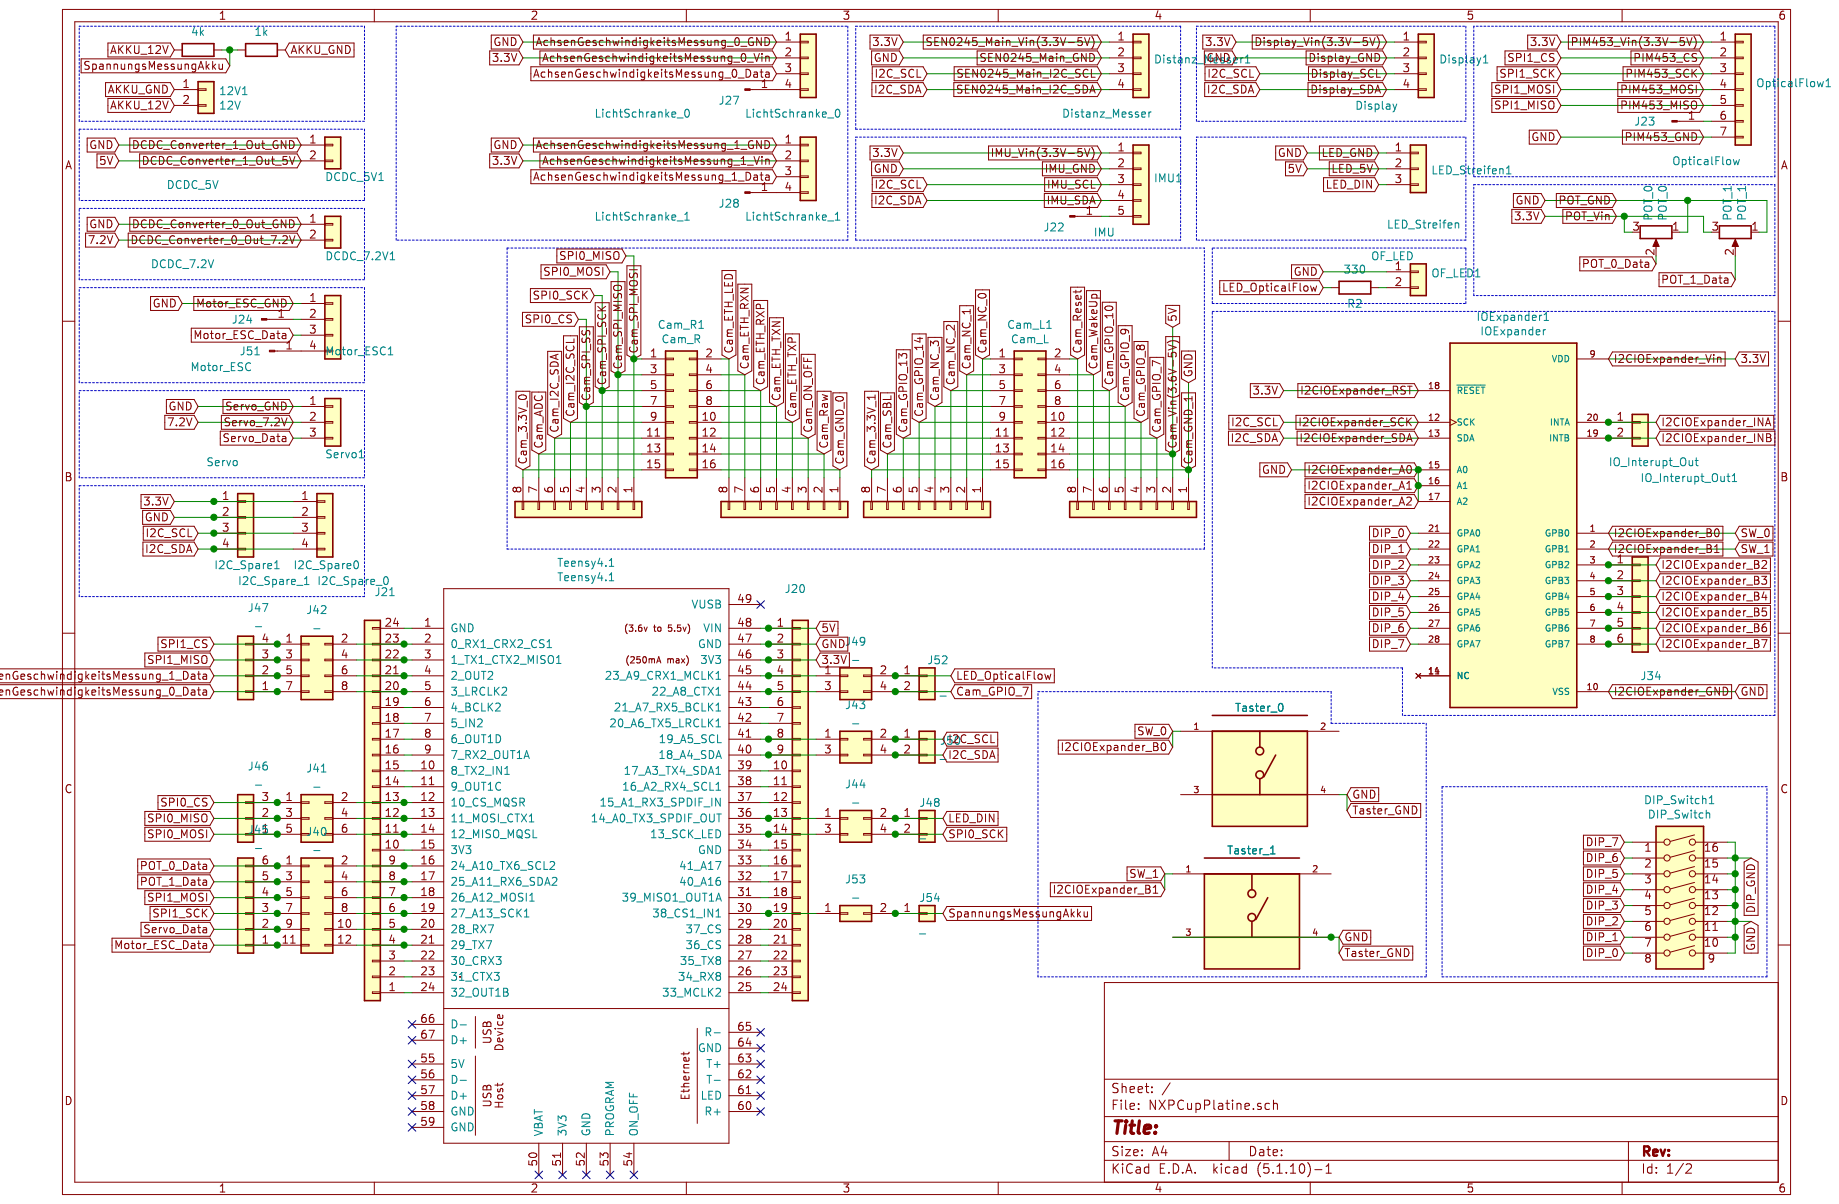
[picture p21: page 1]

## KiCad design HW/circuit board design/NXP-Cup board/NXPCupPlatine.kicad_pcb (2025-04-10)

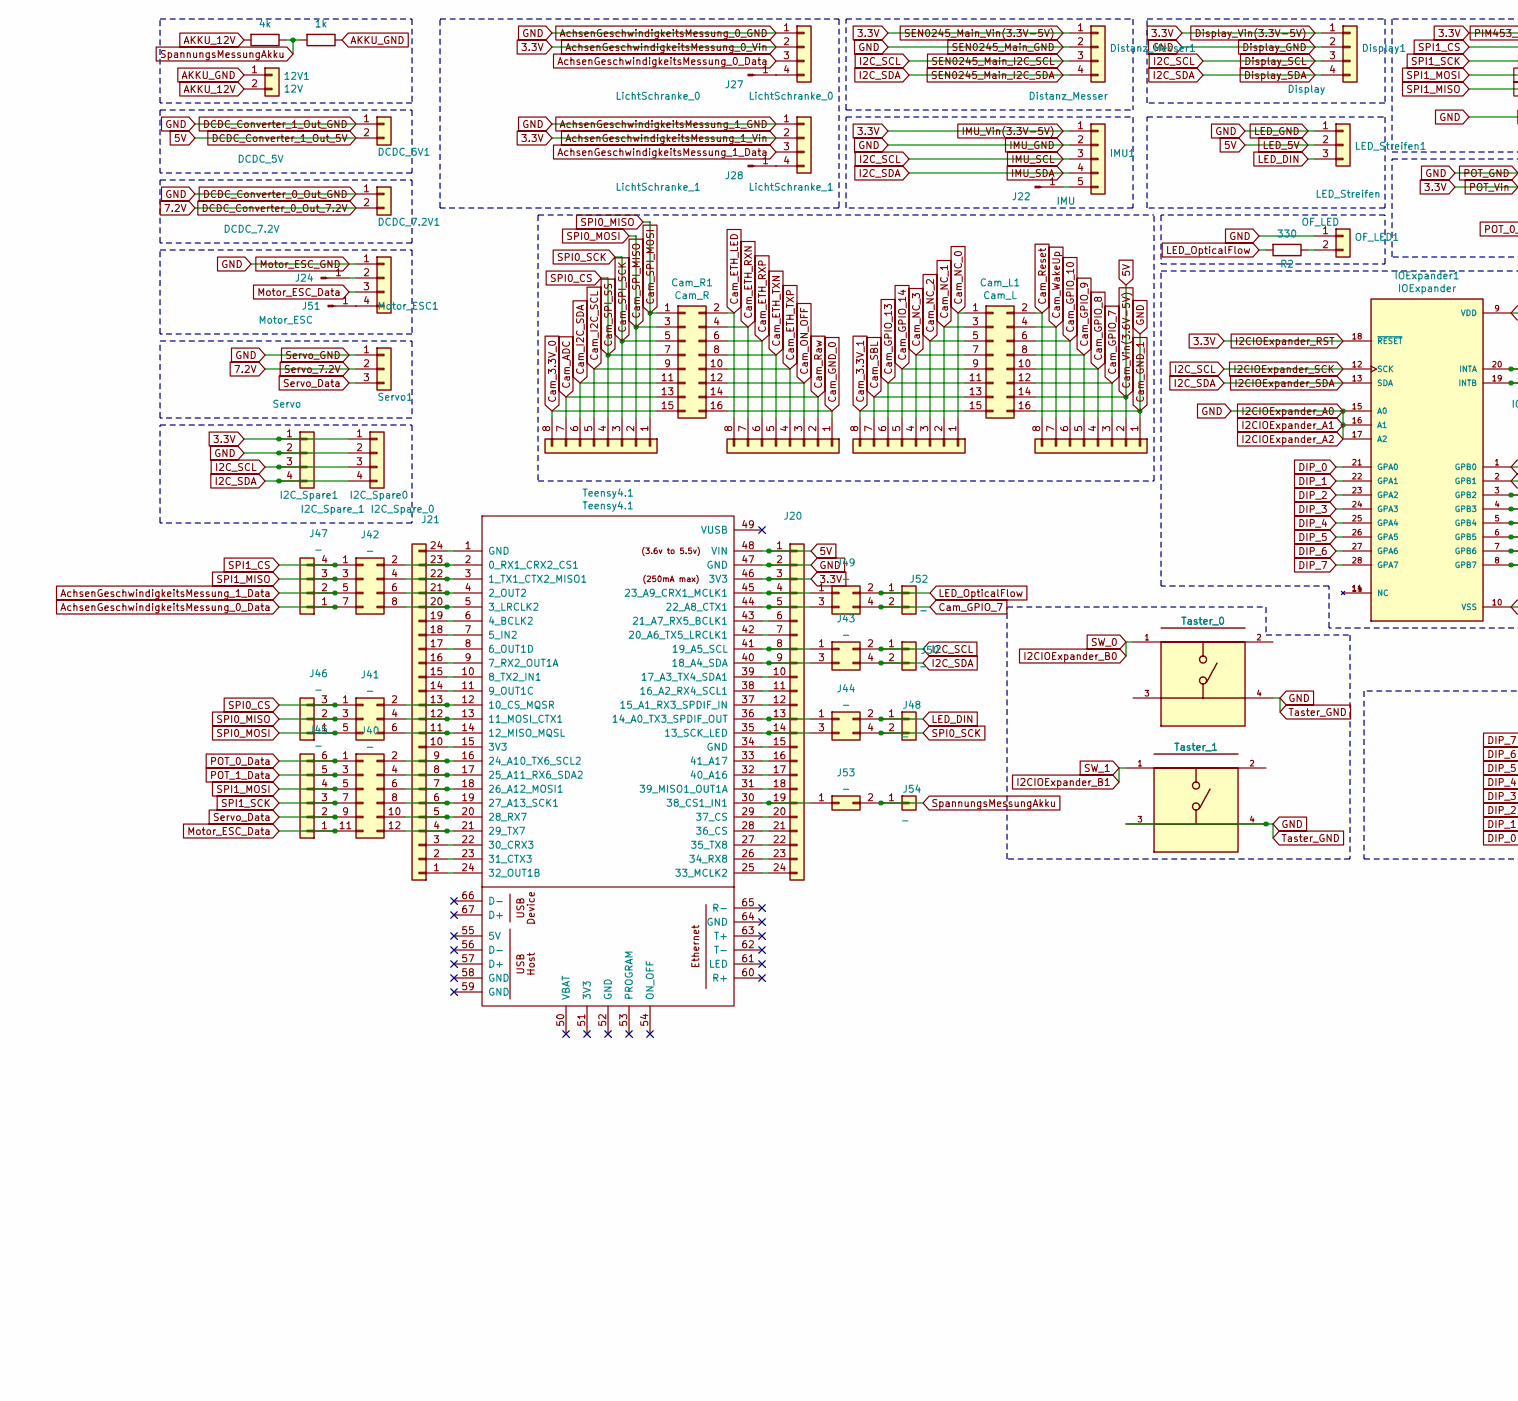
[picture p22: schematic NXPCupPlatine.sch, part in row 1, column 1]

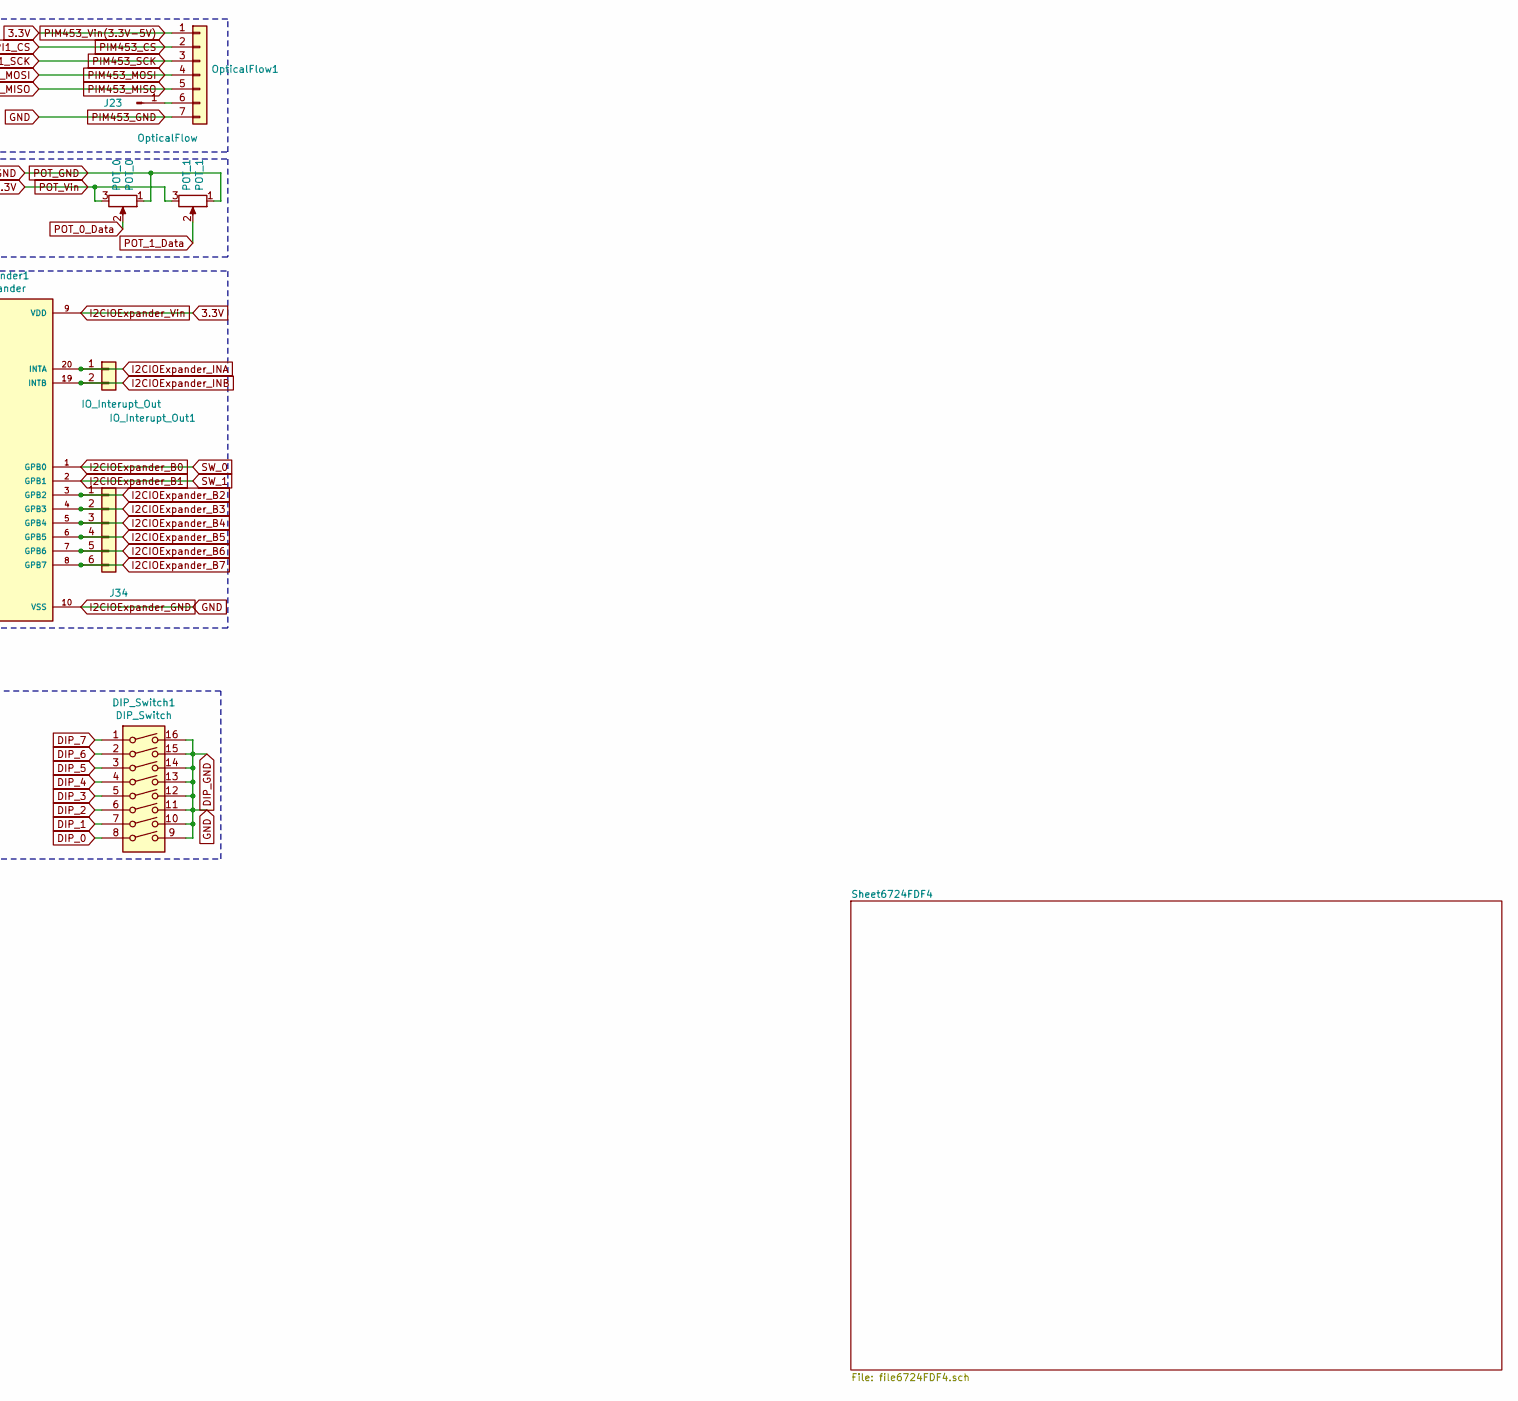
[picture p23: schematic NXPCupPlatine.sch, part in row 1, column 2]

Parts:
12V1: 12V; PinHeader_1x02_P2.54mm_Vertical
Cam_L1: Cam_L; PinHeader_2x08_P2.54mm_Vertical
Cam_R1: Cam_R; PinHeader_2x08_P2.54mm_Vertical
DCDC_5V1: DCDC_5V; PhoenixContact_MSTBA_2,5_2-G_1x02_P5.00mm_Horizontal
DCDC_7.2V1: DCDC_7.2V; PhoenixContact_MSTBA_2,5_2-G_1x02_P5.00mm_Horizontal
DIP_Switch1: DIP_Switch; DIP-16_W7.62mm_LongPads
Display1: Display; PinSocket_1x04_P2.54mm_Vertical
Distanz_Messer1: Distanz_Messer; PinHeader_1x04_P2.54mm_Vertical
I2C_Spare_0: I2C_Spare0; PinHeader_1x04_P2.54mm_Vertical
I2C_Spare_1: I2C_Spare1; PinHeader_1x04_P2.54mm_Vertical
IMU1: IMU; PinHeader_1x05_P2.54mm_Vertical
IOExpander1: IOExpander; DIP787W45P254L3556H508Q28; PARTREV D
IO_Interupt_Out1: IO_Interupt_Out; PinSocket_1x02_P2.54mm_Vertical
J5, J7, J8, J10: PinHeader_1x08_P2.54mm_Vertical
J20, J21: PinHeader_1x24_P2.54mm_Vertical
J22, J23, J24, J27, J28, J51: PinHeader_1x01_P2.54mm_Vertical
J34: PinSocket_1x06_P2.54mm_Vertical
J40: _; PinHeader_2x06_P2.54mm_Vertical
J41: _; PinHeader_2x03_P2.54mm_Vertical
J42: _; PinHeader_2x04_P2.54mm_Vertical
J43, J44, J49: _; PinHeader_2x02_P2.54mm_Vertical
J45: _; PinHeader_1x06_P2.54mm_Vertical
J46: _; PinHeader_1x03_P2.54mm_Vertical
J47: _; PinHeader_1x04_P2.54mm_Vertical
J48, J50, J52: _; PinHeader_1x02_P2.54mm_Vertical
J53: _; PinHeader_2x01_P2.54mm_Vertical
J54: _; PinHeader_1x01_P2.54mm_Vertical
LED_Streifen1: LED_Streifen; PinSocket_1x03_P2.54mm_Vertical
LichtSchranke_0: LichtSchranke_0; PinSocket_1x04_P2.54mm_Vertical
LichtSchranke_1: LichtSchranke_1; PinSocket_1x04_P2.54mm_Vertical
Motor_ESC1: Motor_ESC; PinHeader_1x04_P2.54mm_Vertical
OF_LED1: OF_LED; PinSocket_1x02_P2.54mm_Vertical
OpticalFlow1: OpticalFlow; PinHeader_1x07_P2.54mm_Vertical
POT_0: POT_0; Potentiometer_Alpha_RD901F-40-00D_Single_Vertical
POT_1: POT_1; Potentiometer_Alpha_RD901F-40-00D_Single_Vertical
R0: 4k; R_Axial_DIN0204_L3.6mm_D1.6mm_P1.90mm_Vertical
R1: 1k; R_Axial_DIN0204_L3.6mm_D1.6mm_P1.90mm_Vertical
R2: 330; R_Axial_DIN0204_L3.6mm_D1.6mm_P1.90mm_Vertical
Servo1: Servo; PinHeader_1x03_P2.54mm_Vertical
Taster_0: Taster_0; SW_TS02-66-95-BK-260-LCR-D; PARTREV 1.0
Taster_1: Taster_1; SW_TS02-66-95-BK-260-LCR-D; PARTREV 1.0
Teensy4.1: Teensy4.1; Teensy41

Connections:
3.3V: Display1.1, Distanz_Messer1.1, I2C_Spare_0.1, I2C_Spare_1.1, IMU1.1, IOExpander1.9 (VDD), IOExpander1.18 (~RESET), J20.3, LichtSchranke_0.2, LichtSchranke_1.2, OpticalFlow1.1, POT_0.3, POT_1.3, Teensy4.1.46 (3V3)
5V: Cam_L1.14, DCDC_5V1.2, J10.2, J20.1, LED_Streifen1.2, Teensy4.1.48 (VIN)
7.2V: DCDC_7.2V1.2, Servo1.2
AKKU_12V: 12V1.2, R0.2
AKKU_GND: 12V1.1, R1.1
AchsenGeschwindigkeitsMessung_0_Data: J42.7, J47.1, LichtSchranke_0.3
AchsenGeschwindigkeitsMessung_0_GND: Cam_L1.16, DCDC_5V1.1, DCDC_7.2V1.1, DIP_Switch1.9, DIP_Switch1.10, DIP_Switch1.11, DIP_Switch1.12, DIP_Switch1.13, DIP_Switch1.14, DIP_Switch1.15, DIP_Switch1.16, Display1.2, Distanz_Messer1.2, I2C_Spare_0.2, I2C_Spare_1.2, IMU1.2, IOExpander1.10 (VSS), IOExpander1.15 (A0), IOExpander1.16 (A1), IOExpander1.17 (A2), J10.1, J20.2, LED_Streifen1.1, LichtSchranke_0.1, LichtSchranke_1.1, Motor_ESC1.1, OF_LED1.1, OpticalFlow1.7, POT_0.1, POT_1.1, Servo1.1, Taster_0.4, Taster_1.3, Taster_1.4, Teensy4.1.47 (GND)
AchsenGeschwindigkeitsMessung_1_Data: J42.5, J47.2, LichtSchranke_1.3
Cam_3.3V_0: Cam_R1.15, J5.8
Cam_3.3V_1: Cam_L1.15, J8.8
Cam_ADC: Cam_R1.13, J5.7
Cam_ETH_LED: Cam_R1.2, J7.8
Cam_ETH_RXN: Cam_R1.4, J7.7
Cam_ETH_RXP: Cam_R1.6, J7.6
Cam_ETH_TXN: Cam_R1.8, J7.5
Cam_ETH_TXP: Cam_R1.10, J7.4
Cam_GND_0: Cam_R1.16, J7.1
Cam_GPIO_7: Cam_L1.12, J10.3, J49.4, J52.2
Cam_GPIO_8: Cam_L1.10, J10.4
Cam_GPIO_9: Cam_L1.8, J10.5
Cam_GPIO_10: Cam_L1.6, J10.6
Cam_GPIO_13: Cam_L1.11, J8.6
Cam_GPIO_14: Cam_L1.9, J8.5
Cam_I2C_SCL: Cam_R1.9, J5.5
Cam_I2C_SDA: Cam_R1.11, J5.6
Cam_NC_0: Cam_L1.1, J8.1
Cam_NC_1: Cam_L1.3, J8.2
Cam_NC_2: Cam_L1.5, J8.3
Cam_NC_3: Cam_L1.7, J8.4
Cam_ON_OFF: Cam_R1.12, J7.3
Cam_Raw: Cam_R1.14, J7.2
Cam_Reset: Cam_L1.2, J10.8
Cam_SBL: Cam_L1.13, J8.7
Cam_SPI_MISO: Cam_R1.3, J5.2, J41.5, J46.1
Cam_SPI_MOSI: Cam_R1.1, J5.1, J41.3, J46.2
Cam_SPI_SCK: Cam_R1.5, J5.3, J44.4, J48.2
Cam_SPI_SS: Cam_R1.7, J5.4, J41.1, J46.3
Cam_WakeUp: Cam_L1.4, J10.7
DIP_0: DIP_Switch1.8, IOExpander1.21 (GPA0)
DIP_1: DIP_Switch1.7, IOExpander1.22 (GPA1)
DIP_2: DIP_Switch1.6, IOExpander1.23 (GPA2)
DIP_3: DIP_Switch1.5, IOExpander1.24 (GPA3)
DIP_4: DIP_Switch1.4, IOExpander1.25 (GPA4)
DIP_5: DIP_Switch1.3, IOExpander1.26 (GPA5)
DIP_6: DIP_Switch1.2, IOExpander1.27 (GPA6)
DIP_7: DIP_Switch1.1, IOExpander1.28 (GPA7)
Display_SCL: Display1.3, Distanz_Messer1.3, I2C_Spare_0.3, I2C_Spare_1.3, IMU1.3, IOExpander1.12 (SCK), J43.2, J50.1
Display_SDA: Display1.4, Distanz_Messer1.4, I2C_Spare_0.4, I2C_Spare_1.4, IMU1.4, IOExpander1.13 (SDA), J43.4, J50.2
I2CIOExpander_B0: IOExpander1.1 (GPB0), Taster_0.1
I2CIOExpander_B1: IOExpander1.2 (GPB1), Taster_1.1
I2CIOExpander_B2: IOExpander1.3 (GPB2), J34.1
I2CIOExpander_B3: IOExpander1.4 (GPB3), J34.2
I2CIOExpander_B4: IOExpander1.5 (GPB4), J34.3
I2CIOExpander_B5: IOExpander1.6 (GPB5), J34.4
I2CIOExpander_B6: IOExpander1.7 (GPB6), J34.5
I2CIOExpander_B7: IOExpander1.8 (GPB7), J34.6
I2CIOExpander_INA: IOExpander1.20 (INTA), IO_Interupt_Out1.1
I2CIOExpander_INB: IOExpander1.19 (INTB), IO_Interupt_Out1.2
LED_DIN: J44.2, J48.1, LED_Streifen1.3
LED_OpticalFlow: J49.2, J52.1, R2.2
Motor_ESC_Data: J40.11, J45.1, Motor_ESC1.3
unnamed: IMU1.5, J22.1
unnamed: IOExpander1.11 (NC), IOExpander1.14 (NC)
unnamed: J20.4, J49.1, Teensy4.1.45 (23_A9_CRX1_MCLK1)
unnamed: J20.5, J49.3, Teensy4.1.44 (22_A8_CTX1)
unnamed: J20.6, Teensy4.1.43 (21_A7_RX5_BCLK1)
unnamed: J20.7, Teensy4.1.42 (20_A6_TX5_LRCLK1)
unnamed: J20.8, J43.1, Teensy4.1.41 (19_A5_SCL)
unnamed: J20.9, J43.3, Teensy4.1.40 (18_A4_SDA)
unnamed: J20.10, Teensy4.1.39 (17_A3_TX4_SDA1)
unnamed: J20.11, Teensy4.1.38 (16_A2_RX4_SCL1)
unnamed: J20.12, Teensy4.1.37 (15_A1_RX3_SPDIF_IN)
unnamed: J20.13, J44.1, Teensy4.1.36 (14_A0_TX3_SPDIF_OUT)
unnamed: J20.14, J44.3, Teensy4.1.35 (13_SCK_LED)
unnamed: J20.15, Teensy4.1.34 (GND)
unnamed: J20.16, Teensy4.1.33 (41_A17)
unnamed: J20.17, Teensy4.1.32 (40_A16)
unnamed: J20.18, Teensy4.1.31 (39_MISO1_OUT1A)
unnamed: J20.19, J53.1, Teensy4.1.30 (38_CS1_IN1)
unnamed: J20.20, Teensy4.1.29 (37_CS)
unnamed: J20.21, Teensy4.1.28 (36_CS)
unnamed: J20.22, Teensy4.1.27 (35_TX8)
unnamed: J20.23, Teensy4.1.26 (34_RX8)
unnamed: J20.24, Teensy4.1.25 (33_MCLK2)
unnamed: J21.1, Teensy4.1.24 (32_OUT1B)
unnamed: J21.2, Teensy4.1.23 (31_CTX3)
unnamed: J21.3, Teensy4.1.22 (30_CRX3)
unnamed: J21.4, J40.12, Teensy4.1.21 (29_TX7)
unnamed: J21.5, J40.10, Teensy4.1.20 (28_RX7)
unnamed: J21.6, J40.8, Teensy4.1.19 (27_A13_SCK1)
unnamed: J21.7, J40.6, Teensy4.1.18 (26_A12_MOSI1)
unnamed: J21.8, J40.4, Teensy4.1.17 (25_A11_RX6_SDA2)
unnamed: J21.9, J40.2, Teensy4.1.16 (24_A10_TX6_SCL2)
unnamed: J21.10, Teensy4.1.15 (3V3)
unnamed: J21.11, J41.6, Teensy4.1.14 (12_MISO_MQSL)
unnamed: J21.12, J41.4, Teensy4.1.13 (11_MOSI_CTX1)
unnamed: J21.13, J41.2, Teensy4.1.12 (10_CS_MQSR)
unnamed: J21.14, Teensy4.1.11 (9_OUT1C)
unnamed: J21.15, Teensy4.1.10 (8_TX2_IN1)
unnamed: J21.16, Teensy4.1.9 (7_RX2_OUT1A)
unnamed: J21.17, Teensy4.1.8 (6_OUT1D)
unnamed: J21.18, Teensy4.1.7 (5_IN2)
unnamed: J21.19, Teensy4.1.6 (4_BCLK2)
unnamed: J21.20, J42.8, Teensy4.1.5 (3_LRCLK2)
unnamed: J21.21, J42.6, Teensy4.1.4 (2_OUT2)
unnamed: J21.22, J42.4, Teensy4.1.3 (1_TX1_CTX2_MISO1)
unnamed: J21.23, J42.2, Teensy4.1.2 (0_RX1_CRX2_CS1)
unnamed: J21.24, Teensy4.1.1 (GND)
unnamed: J23.1, OpticalFlow1.6
unnamed: J24.1, Motor_ESC1.2
unnamed: J27.1, LichtSchranke_0.4
unnamed: J28.1, LichtSchranke_1.4
unnamed: J51.1, Motor_ESC1.4
unnamed: OF_LED1.2, R2.1
PIM453_CS: J42.1, J47.4, OpticalFlow1.2
PIM453_MISO: J42.3, J47.3, OpticalFlow1.5
PIM453_MOSI: J40.5, J45.4, OpticalFlow1.4
PIM453_SCK: J40.7, J45.3, OpticalFlow1.3
POT_0_Data: J40.1, J45.6, POT_0.2
POT_1_Data: J40.3, J45.5, POT_1.2
Servo_Data: J40.9, J45.2, Servo1.3
SpannungsMessungAkku: J53.2, J54.1, R0.1, R1.2

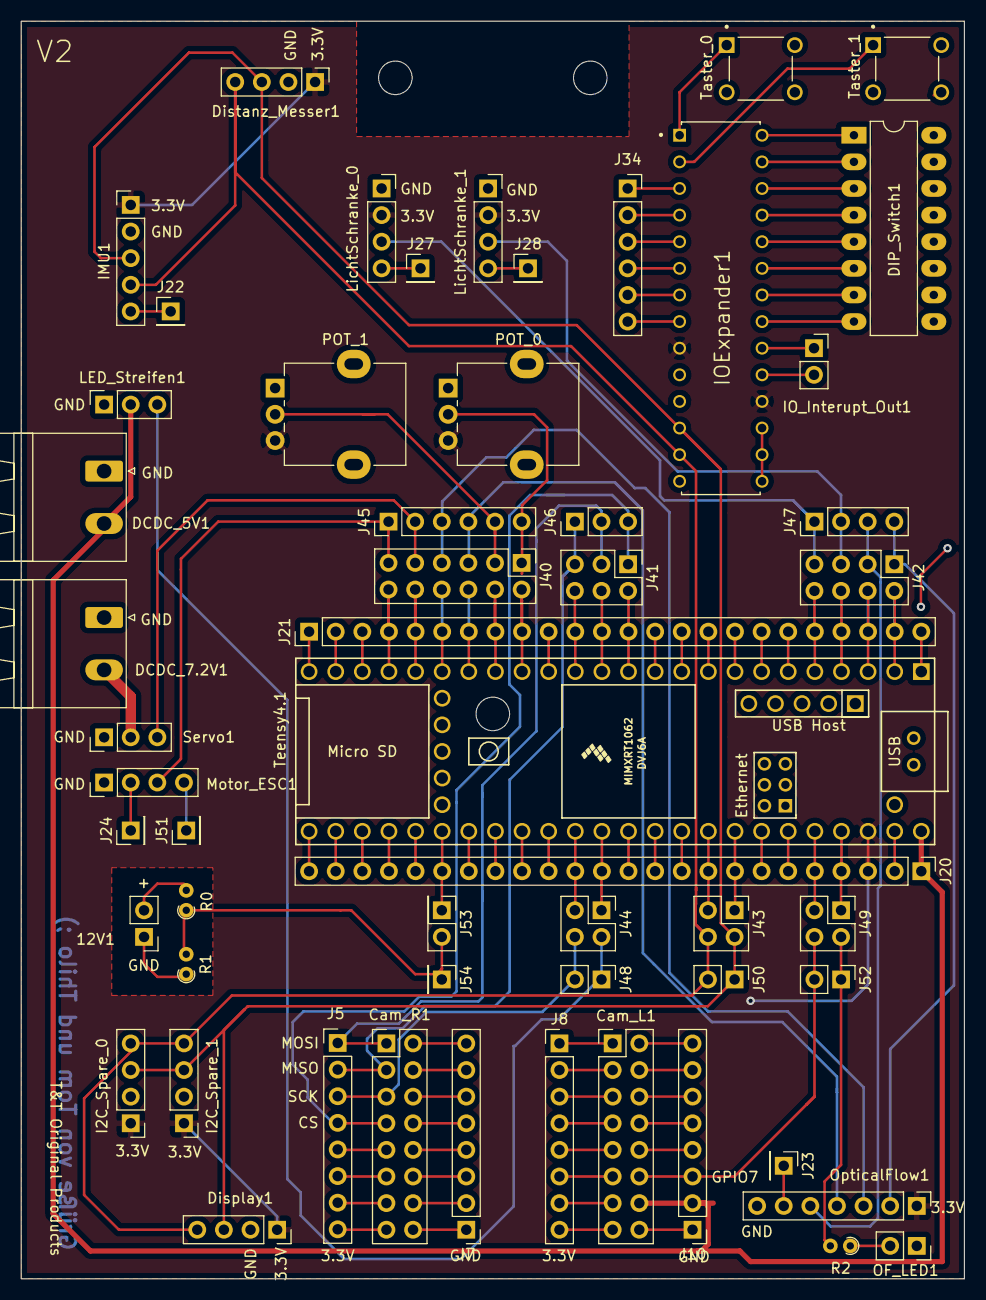
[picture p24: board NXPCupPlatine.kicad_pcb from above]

Board: 2 copper layers, 90.0 x 120.0 mm, 55 parts (0 on the bottom side), 122 nets.

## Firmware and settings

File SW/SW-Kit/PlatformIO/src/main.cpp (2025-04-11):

/**
 * general main file with setup and loop
 * calls the required methods of the implemented modules
 */
#include <Arduino.h>
#include <Wire.h>

#include "drivingControl/drivingControl.h"
#include "carLogic/carLogic.h"
#include "cameraAnalysis/camera.h"



void setup() {

  Serial.begin(115200);

  DrivingControl::setup();
  CameraAnalysis::OpenMVCam::setup();

}

void loop() {
  CarLogic::runCarLogic();
  CameraAnalysis::OpenMVCam::updateImage();
}

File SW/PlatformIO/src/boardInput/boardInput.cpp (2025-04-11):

/**
 * Board Input - definition
 * 
 * Handles everything belonging to the board inputs like the poti, button
 * and dipSwitch Values. This includes the use of the IO-Expander
 * to get the values of the Buttons and DipSwitch.
 * 
 * using the Library: Adafruit_MCP23017.h
 * https://github.com/adafruit/Adafruit-MCP23017-Arduino-Library
 * 
 * @author Tom Seiffert
 */
#include "boardInput/boardInput.h"
#include "Adafruit_MCP23X17.h"
#include "configuration/globalConfig.h"

namespace BoardInput {

    Data data;
    Adafruit_MCP23X17 ioExpander;
    
    //forward declaration
    void setupIoExpander();
    void setupData();
    int readPoti(int poti);
    uint8_t readButton(int button);
    uint8_t readDipSwitch();

    /* ------- public known methods ------------------ */

    // comment in .h file
    void setup() {
        setupIoExpander();
        setupData();
    }

    // comment in .h file
    // ToDo: analog Read... take time - if necessary split into stept or interupting
    void update() {
        data.poti1 = readPoti(POTI1);
        data.poti2 = readPoti(POTI2);
        data.button1 = readButton(IO_EX_BUTTON1);
        data.button2 = readButton(IO_EX_BUTTON2);
        data.dipSwitch = readDipSwitch();
    }

    // comment in .h file
    void printData() {
        #ifdef CONSOLE
            String dataToPrint = "";
            dataToPrint = dataToPrint + "Poti 1: " + data.poti1 + " Poti 2: " + data.poti2 
            + " Button 1: " + data.button1 + " Button 2 " + data.button2 + " Dip Switch: " + data.dipSwitch;
            CONSOLE.print ("Board Input | ");
            CONSOLE.println(dataToPrint);
        #endif
    }

    // comment in .h file
    Data* getData() {
        return &data;
    }

    // comment in .h file
    bool getSingleDipswitchValue(DipSwitchEnum aDipSwitch) {
        return data.dipSwitch & (uint8_t)aDipSwitch;
    }


    /* ------- privat - public unknown methods ------- */

    /**
     * setup the IOExpander with the given methods
     * - begin i2C connection
     * - initiate the pinmode for the used pins
     */
    void setupIoExpander() {
        if(ioExpander.begin_I2C()) {
            #ifdef CONSOLE
                CONSOLE.println("BoardInput: IO-Expander setup sucessfull");
            #endif
        }
        else {
            #ifdef CONSOLE
                CONSOLE.println("BoardInput: IO-Expander setup error");
            #endif
        }

        ioExpander.pinMode(IO_EX_BUTTON1, INPUT_PULLUP);
        ioExpander.pinMode(IO_EX_BUTTON2, INPUT_PULLUP);
        ioExpander.pinMode(IO_EX_DIPSWITCH1, INPUT_PULLUP);
        ioExpander.pinMode(IO_EX_DIPSWITCH2, INPUT_PULLUP);
        ioExpander.pinMode(IO_EX_DIPSWITCH3, INPUT_PULLUP);
        ioExpander.pinMode(IO_EX_DIPSWITCH4, INPUT_PULLUP);
    }

    /**
     * setup the data struct
     * - sets all values to 0
     */
    void setupData() {
        data.poti1 = 0;
        data.poti2 = 0;
        data.button1 = 0;
        data.button2 = 0;
        data.dipSwitch = 0;
    }

    /**
     * read poti data
     * @param poti: the poti to read
     * @return: the poti value
     */
    int readPoti(int poti) {
        return analogRead(poti);
    }

    /**
     * read button Data
     * @param button: the button to read
     * @return: the button value
     */
    uint8_t readButton(int button) {
        return !ioExpander.digitalRead(button);
    }

    /**
     * read the dip switch
     * - create decimal representation of dip switch values 
     * @return: the value of all switches together as decimal number
     */
    uint8_t readDipSwitch() {
        uint8_t dipSwitchvalue = 15;
        dipSwitchvalue -= ioExpander.digitalRead(IO_EX_DIPSWITCH1) * 1;
        dipSwitchvalue -= ioExpander.digitalRead(IO_EX_DIPSWITCH2) * 2;
        dipSwitchvalue -= ioExpander.digitalRead(IO_EX_DIPSWITCH3) * 4;
        dipSwitchvalue -= ioExpander.digitalRead(IO_EX_DIPSWITCH4) * 8;
        return dipSwitchvalue;
    }
}

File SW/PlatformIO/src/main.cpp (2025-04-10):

#include <Arduino.h>
#include <Wire.h>

#include "configuration/globalConfig.h"

#include "cameraAnalysis/cameraAnalysis.h"
#include "cameraAnalysis/trackCenterAnalysis.h"
#include "dataVisualization/dataVisualization.h"
#include "boardInput/boardInput.h"
#include "drivingControl/drivingControl.h"
#include "sensors/sensors.h"
#include "carLogic/carLogic.h"
#include "timingControl/timingControl.h"

void checkingForErrors(); //ToDo: Just to Debug

bool setupSensor = true;

void setup() {
  #ifdef CONSOLE
    CONSOLE.begin(115200);
  #endif
  delay(1000);

  Wire.begin();
  Wire1.begin();
  
  //ToDo: remove - avoid i2c IO-Expander
  pinMode(DIPSWITSCH1, INPUT_PULLUP);
  pinMode(DIPSWITSCH2, INPUT_PULLUP);
  pinMode(DIPSWITSCH3, INPUT_PULLUP);
  pinMode(DIPSWITSCH4, INPUT_PULLUP);

  DataVisualization::setup();
  CameraAnalysis::setup();
  BoardInput::setup();
  DrivingControl::setup();
  TimingControl::setup();
  CarLogic::defineTimedTasks();
  Sensors::setup();

  DataVisualization::Display::showsetupDone();
  #ifdef CONSOLE
    CONSOLE.println("Main | Setup Done!");
  #endif
}

void loop() {
  BoardInput::update(); //toDo Move into CarLogc - umsetzen (Anpassen an Diagramm!)
  CameraAnalysis::analyse(true);
  CarLogic::runCarLogic();
  TimingControl::runTasks();
  

  if(CameraAnalysis::TrackCenterAnalysis::finishLineDetected) {

    if (setupSensor) {
      setupSensor = false;

      TimingControl::createTask([](TimingControl::Task* self) {
        Sensors::updateUsedData();
      }, 30, true, true);

    }
    //Sensors::printData();
  }

  //Sensors::printData();
  //CONSOLE.println(micros());
}

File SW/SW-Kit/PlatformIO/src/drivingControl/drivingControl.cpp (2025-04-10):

/**
 * driving control - definition
 * 
 * handels everything to control the car driving. 
 * This includes functions to setup engine and servo and
 * the general control of them to drive correctly.
 * 
 * @author Tom Seiffert
 */
#include "drivingControl/drivingControl.h"
#include "drivingControl/engine.h"
#include "drivingControl/servo.h"
#include "carLogic/carLogic.h"

namespace DrivingControl {
    
    /* ------- public known methods ------------------ */

    //comment in .h file
    void setup() {
        SteeringServo::setup();
        Engine::setup();
    }

    //comment in .h file
    void drive(uint8_t speed, int steeringAngle) {
            Engine::setSpeed(speed);
            SteeringServo::setSteeringAngle(steeringAngle);
    }
}

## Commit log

2024-07-29 add some camera research
2024-08-12 add new research (camera, display...)
2024-08-17 start defining Hardware-Kit (Teensy + Cam)
2024-08-20 new research (camera, car racing kit)
2024-08-26 update research (motor links)
2024-08-27 add servo research
2024-09-18 initiate project with blink on teensy
2024-09-23 component test optical flow
2024-09-23 rework single component tests
    [globalConfig.h]
2024-09-24 component test servo (not testet!)
2024-09-24 component test motor (not testet!)
2024-09-24 component test IMU (not testst!)
2024-09-30 start test for cam spi to teensy
2024-10-03 add spi test script for single data transfer
2024-10-03 rename spi test scritps
2024-10-17 add Example for Accespoint Asynccontrol of the camera
2024-10-28 update pin config for new circuit Board
2024-10-30 motor tests
2024-10-30 preperation for spi
2024-10-30 add spi examplescript (Cam)
2024-10-30 working teensy spi slave
2024-10-30 remove spi single byte test
2024-11-07 update imu lib and add license
2024-11-07 cleanup single components cam, display, imu, io-expander
2024-11-07 clean up single components motor, servo, poti, ToF, IR - add readme
2024-11-07 rename pin defines
2024-11-21 add example SPI Write Lines
2024-11-21 fix IO Expander warning
    [globalConfig.h]
2024-11-21 first attempt of camera analysis
2024-11-21 print of the img and img lines via cameraAnalysis
2024-11-21 fix spi transfer of gray image + add pixelprint method (open MV Cam)
    [camera_OPENMVCAMRT1062.cpp]
2024-11-22 add basic implementation of calculate track center
2024-12-10 rework single components - namespace
    [camera_OPENMVCAMRT1062.cpp, globalConfig.h, main.cpp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]
2024-12-10 add led Strip
2024-12-10 fixes to compile - currently dont driving
    [camera_OPENMVCAMRT1062.cpp, main.cpp, servo_REELYS2210.cpp]
2024-12-11 fixes so car can drive like before
    [main.cpp, servo_REELYS2210.cpp]
2024-12-11 start with boardInput Control
2024-12-19 add implementation to board Input Control for setup, update, ...
2024-12-19 more data Visualisation (setup, set Led Color....)
2024-12-19 start structure of DataVis and Board Input working
2024-12-27 comment board input + tenary Operation (engineEnabled)
2025-01-02 start structure for driving control (servo, esc)
2025-01-02 Update Board Input for use of single Dipswitsch State
2025-01-02 start sensor structre (ToF distance)
2025-01-02 add servo enable control
2025-01-02 correct steering control
2025-01-02 structure optical flow
2025-01-02 add imu sensor
2025-01-02 identify servo bug (led problem - no solution)
    [drivingControl.cpp, main.cpp]
2025-01-03 rename cameraAnalysis
2025-01-04 rework to structure with namespaces
    [boardInput.cpp, camera_OPENMVCAMRT1062.cpp, engine.cpp]
2025-01-13 start reworking camera structure
    [camera_OPENMVCAMRT1062.cpp, main.cpp]
2025-01-13 clean Up cameraAnalysis
2025-01-13 cleanup camera files
2025-01-13 rename camera file
2025-01-17 change the led library to FastLed
2025-01-17 Update Single Components to new LED Library
2025-01-17 Update README.md
    Link Fas LED
2025-01-17 update camera code of single Component
2025-01-17 Licens and readme for SPI Slave lib
2025-01-17 comment boardInput
2025-01-18 comment ledstrip
2025-01-18 comment servo
2025-01-18 comment imu and use motionData Struct
2025-01-18 comment optical flow
2025-01-18 comment sensor
2025-01-20 working test imu data struct
2025-01-22 change steering and engine enabled
2025-01-23 test optical Flow values
2025-01-29 driving faster than before - servo and camera analysis changes
2025-02-18 change sleep time (SPI) + some tests
2025-02-21 error handling (try to figure out why teensy stop)
    [main.cpp]
2025-03-01 spi tests on firmware
2025-03-05 clean up boardInput, configuration, datavisualisation
2025-03-05 clean up sensors
2025-03-05 split Cameraanalysis in multiple files
2025-03-05 start cleanup camera
2025-03-05 rework camera swap buffer - driving
    [camera.cpp]
2025-03-06 prepare teensy for analyse on camera
2025-03-06 more analyse stuff on teensy
2025-03-07 driving test with new camera Analysis
2025-03-07 saving camera video on sd card
2025-03-07 video Testing camera analysis
2025-03-08 clean up camera scripts finished
2025-03-12 board input data public
2025-03-14 firmware changes to detect if track centers is not on track anymore
2025-03-14 clean up single component servo
2025-03-15 add comments to SPI-Slave lib
2025-03-19 inlcude timed Tasks vor leds and speed + add display visualisation
2025-03-26 clean up teensy spi
2025-03-26 bugfix for trackCenter[1] byte
    [nxpcup.c]
2025-03-26 try steering optimation (with far line ahead)
2025-03-27 update to new sensor
2025-03-27 skip frames if nothing to see
    [nxpcup.c]
2025-03-31 update firmware module (fix finishline but) + fix steering Offset left
    [nxpcup.c]
2025-04-01 remove error check in main
    [main.cpp]
2025-04-01 switch dip-switsch to Teensy pins
2025-04-01 add firmware visualisation of steering lines
2025-04-01 finischline detection test + configure cutting curves + change Tof i2c
2025-04-01 try to fix tof bug - better driving (request tof just if finish found
    [globalConfig.h, main.cpp, trackCenterAnalysis.cpp]
2025-04-02 fix new cross test
    [nxpcup.c]
2025-04-03 Add speed configuration via dip switch
2025-04-10 add board design documentation
    [NXPCupPlatine-B_Cu.gbr, NXPCupPlatine-B_Mask.gbr, NXPCupPlatine-B_Paste.gbr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]
2025-04-10 add 3d models
    [Gussform_Außen1.3mf, Gussform_Außen2.3mf, Gussform_Innenrad.3mf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]
2025-04-10 rename optical flow 3d model
    [Halterung_Optical_Flow.3mf, Halterung_Optical_Flow.FCStd, Halterung_Optical_Flow.stl]
2025-04-10 include config to servo
2025-04-11 clean up analysis on teensy
